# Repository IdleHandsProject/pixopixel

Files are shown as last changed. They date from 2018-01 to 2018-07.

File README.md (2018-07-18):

# The PIXO Pixel
PIXO Pixel is a 16 x 16 RGB LED display that runs off of an ESP32.

This project is open source! 

If you want to build this yourself, you can find the Bill of Materials [here](https://www.findchips.com/org/10-open-hardware/list/85998-pixo-pixel-esp-board-and-led-board) on FindChips.

I have submitted a pull request to the Arduino-ESP32 github: https://github.com/espressif/arduino-esp32 to have the PIXO Pixel have its own board file. This will ensure the pinout that was used will match the pin declartion on the board. In the meantime, please use the "Adafruit Feather ESP32" in the board manager, as the pinout is the same.

## Flashing Firmware Instructions
1. You need to have the current version of the [Arduino IDE](https://arduino.cc) installed
2. Ensure that you have the [Arduino ESP32 Boards](https://github.com/espressif/arduino-esp32) installed (This library is currently broken, a workaround has been found [Here](https://github.com/espressif/arduino-esp32/issues/1559))
3. Various other libraries are required for the example firmware; they are listed below under "Libraries used in Example Firmware"
4. Connect your pixo pixel to your computer and start Arduino
5. Under the "Tools" menu, select "Board->Adafruit ESP32 Feather"; Leave Flash frequency and Upload speed the default
6. Under Port, select the device your pixo is communicating over
7. Compile and upload
8. When the Arduino console says "Connecting....", press and hold both the boot and reset buttons simultaniously for 1 second; then release both buttons
9. You should start to see output about flashing
10. When the flash is complete, press the reset button on the pixo to start your new firmware

[Here](https://youtu.be/dVT4Nei8qHg) is a video of Sean going into detail demonstrating some of the examples

## Libraries used in Example Firmware
Install these to your sketchbook's `libraries` folder, usually located in `YOUR HOME/Documents/Arduino`

* [Adafruit GFX](https://github.com/adafruit/Adafruit-GFX-Library)
* [Adafruit DotStar](https://github.com/adafruit/Adafruit_DotStar)
* [Adafruit DotStar Matrix](https://github.com/adafruit/Adafruit_DotStarMatrix)
* [ArduinoJson](https://github.com/bblanchon/ArduinoJson)
* [i2cdevlib](https://github.com/jrowberg/i2cdevlib)

**Note** Arduino IDE was complaining about i2cdevlib being invalid as the installation instructions are a bit unclear.
It seems that the ESP32 is not officially supported for use with these libraries, and I had to apply a patch ([#367](https://github.com/jrowberg/i2cdevlib/pull/367)) to get no compile errors.

### Patching I2Cdev and MPU6050 Libraries
1. Download i2cdevlib and extract the zip file
2. Inside the i2cdevlib/Arduino folder, copy `I2Cdev` and `MPU6050` folders to your `libraries` folder
3. Edit `libraries/I2Cdev/I2Cdev.cpp`, and immedietly under `#include "I2Cdev.h"`, add the following
```
#ifdef ARDUINO_ARCH_ESP32
#define BUFFER_LENGTH I2C_BUFFER_LENGTH
#endif
```
4. Edit `libraries/MPU6050/MPU6050_6Axis_MotionApps20.h` and add the following right above the `DEBUG` section
```
#ifndef ARDUINO_ARCH_ESP32
    typedef void prog_void;
    typedef char prog_char;
    typedef unsigned char prog_uchar;
    typedef int8_t prog_int8_t;
    typedef uint8_t prog_uint8_t;
    typedef int16_t prog_int16_t;
    typedef uint16_t prog_uint16_t;
    typedef int32_t prog_int32_t;
    typedef uint32_t prog_uint32_t;
#endif
```
5. Restart Arduino

There's a whole bunch of other commits in here, but this seems mostly to be a mix of: feature adding, bug fixing, and various other changes that may or may not be related. Feel free to experiment with these at your own discretion.

## Kickstarter - Success
This was a [Make100 Kickstarter](https://www.kickstarter.com/projects/idlehandsdev/pixo-pixel-an-esp32-based-iot-rgb-display-for-make) that was recently fulfilled

Kickstarter Vid (https://youtu.be/XT5R4Tftu7k)

[Completion Video](https://youtu.be/YA3uAYVbMNc)

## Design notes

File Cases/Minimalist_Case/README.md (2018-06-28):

# A Minimalist Case for the PIXO Pixel

There is only a port for power - buttons and USB programming are covered up with this case, but it could be easily modified to make them more accessible.

This case can also be downloaded from [Thingiverse](https://www.thingiverse.com/thing:2974680)

## Assembly Instructions

1) Remove all hardware that came with the PIXO Pixel
2) Screw 4x M3x6 standoffs into the base of the "Case" part and secure with an M3 nut
3) Place bottom board of PIXO Pixel into case, and secure with 4x M3x15 standoffs
4) Place upper board of PIXO Pixel on standoffs
5) Place "Bezel" part on top of upper board
6) Secure with M3 screws of appropriate length (I used M3x12 button head screws)

Plug in power and enjoy!

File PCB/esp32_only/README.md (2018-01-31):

# ESPEverywhere
ESP8266 Special Make/100 Kickstarter Edition

ESP Everywhere

Check out why this board exists here:
https://www.youtube.com/watch?v=67Kh_ikb-ds

The ESP Everywhere was made to take part in the Kickstarter Make/100 Campaign
You can get 1 of 100 boards assembled by me. Or you can Make your own.
Kickstarter is here:
https://www.kickstarter.com/projects/idlehandsdev/esp-everywhere-kickstarter-special-make-100

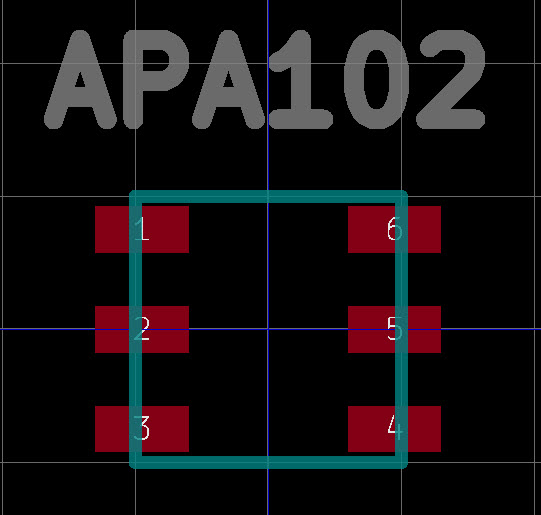
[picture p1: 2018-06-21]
PCB/pixel/Docs/new_apa102.jpg

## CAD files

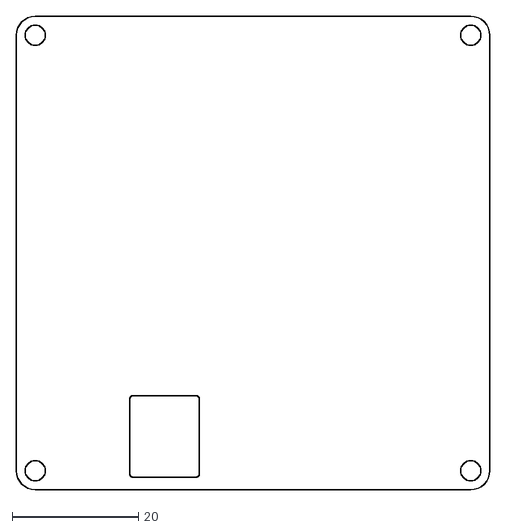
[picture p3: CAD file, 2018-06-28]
CAD/PIXO_ESP.dxf
75.0 x 75.0

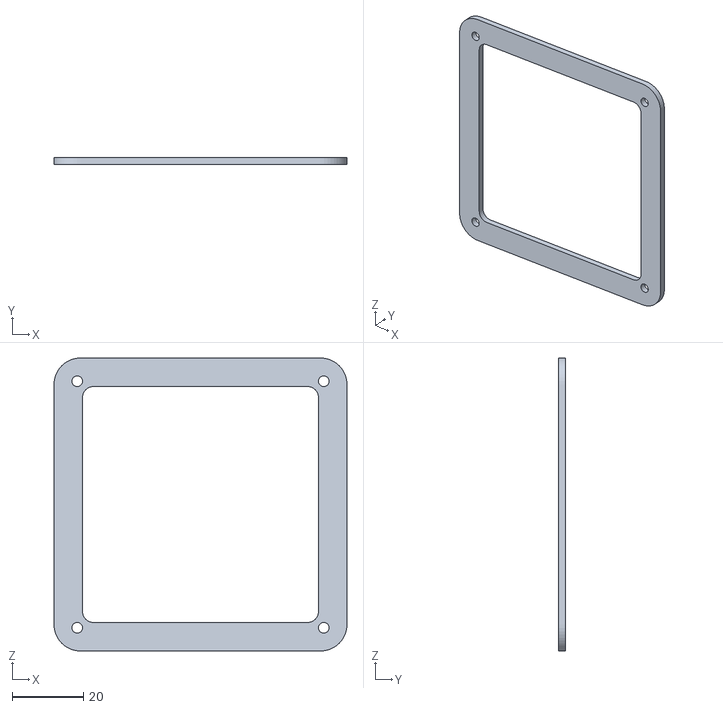
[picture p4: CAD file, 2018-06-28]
Cases/Minimalist_Case/PIXO_Bezel.stl
82.0 x 2.00 x 82.0

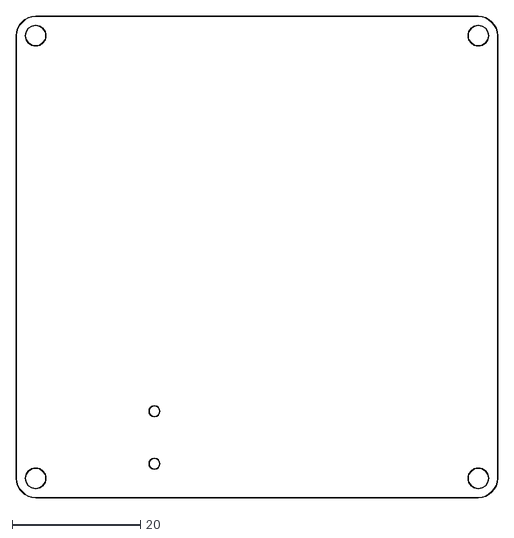
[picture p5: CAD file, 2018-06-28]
CAD/PIXO_Pixel.dxf
75.0 x 75.0

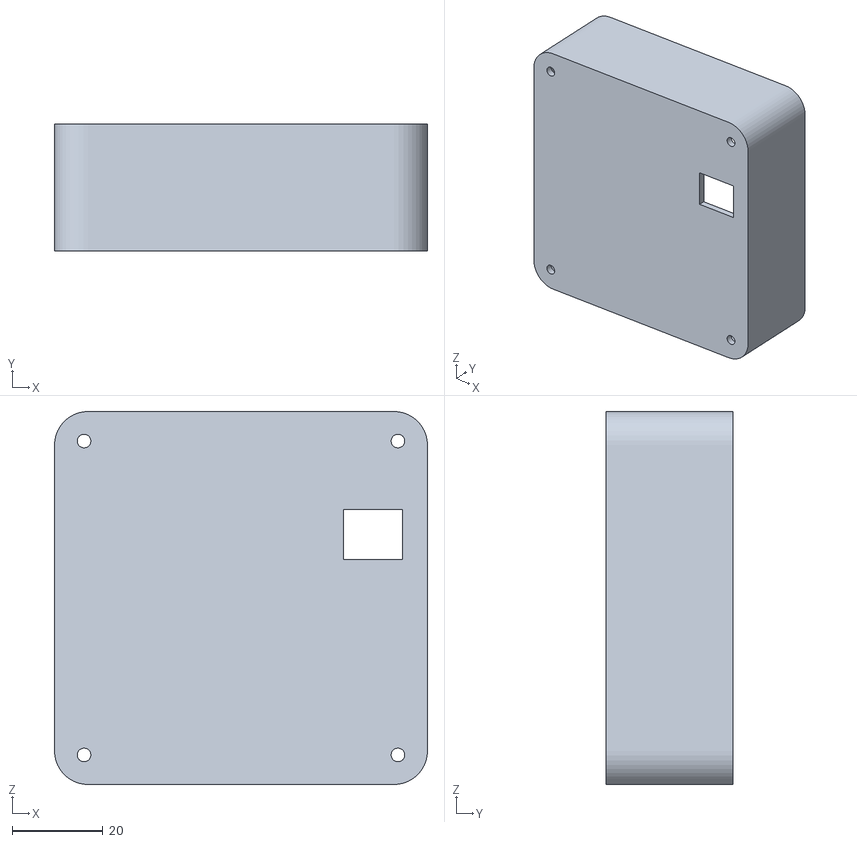
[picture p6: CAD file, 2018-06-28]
Cases/Minimalist_Case/PIXO_Case.stl
82.0 x 28.0 x 82.0

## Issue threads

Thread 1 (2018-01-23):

Switch Pins on DIODES D1 D2

hodginsa, 2018-01-23:
As always, diodes are reversed compared to the directional line.

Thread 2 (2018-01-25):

No Ground on Pixel 236

hodginsa, 2018-01-25:

hodginsa, 2018-02-20:
Ground has been fixed.

Closed 2018-02-20.

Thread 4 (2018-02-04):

Ground surrounding antenna

janekm, 2018-02-04:
While the ground is cleared right underneath the antenna, there is still a ground loop surrounding it. It would be better to move the module right up to the edge of the PCB, or at least clear the ground plane right up to the edge of the PCB, for antenna performance. Great project btw, I've also looked at these little LEDs and thought it'd be great to make a little display with them :)

hodginsa, 2018-02-20:
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
The ground plane was already to the edge, but I may be misinterpreting what you mean. Anyway, I have also widened the keepout to free up the antenna a bit more. :) Thanks!

janekm, 2018-02-21:
I think I was looking at an old version of the gerbers, sorry. Certainly looks better now!

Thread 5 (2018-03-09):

'A1' was not declared in this scope

LilyGO, 2018-03-09:
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

chunkysteveo, 2018-03-09:
Looks like he's used a different board declaration for the "pinouts".

Steve

hodginsa, 2018-04-19:
When I was testing I was using the Adafruit ESP32 Feather. However, that analog pin is just for "random" use, so any unconnected analog pin will work.

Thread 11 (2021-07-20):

Can it be implemented in a project about Parchis/Parks?

ImanCol, 2021-07-20:
I am doing a project that uses Arduino and we came up with converting a Ludo game board called Parchis / Parques with ws2812b LEDs.

In total, it would take us almost 600 of these RGB LEDs.  And I'm scratching my head on how to turn each 1 through a Bluetooth module to an Apple where it will contain the intelligence of the programmed game.  The idea is that every time someone moves a tile, the board with the LEDs reflects the same movement.

I don't really know if Arduino can handle that much data so I was wondering if your project can handle this with ease.  Although I have not fully studied its operation and handle a large number of LEDs, I appreciate any help.

https://upload.wikimedia.org/wikipedia/commons/e/e1/Parcheesi.svg

chunkysteveo, 2021-07-20:
The ESP is more than capable of turning on and off 600 addressable LEDs. But the Pixo only has 256 leds, not 600.

ImanCol, 2021-07-25:
I have researched it and it seems ideal for the project.  Thanks.

Closed 2021-07-25.

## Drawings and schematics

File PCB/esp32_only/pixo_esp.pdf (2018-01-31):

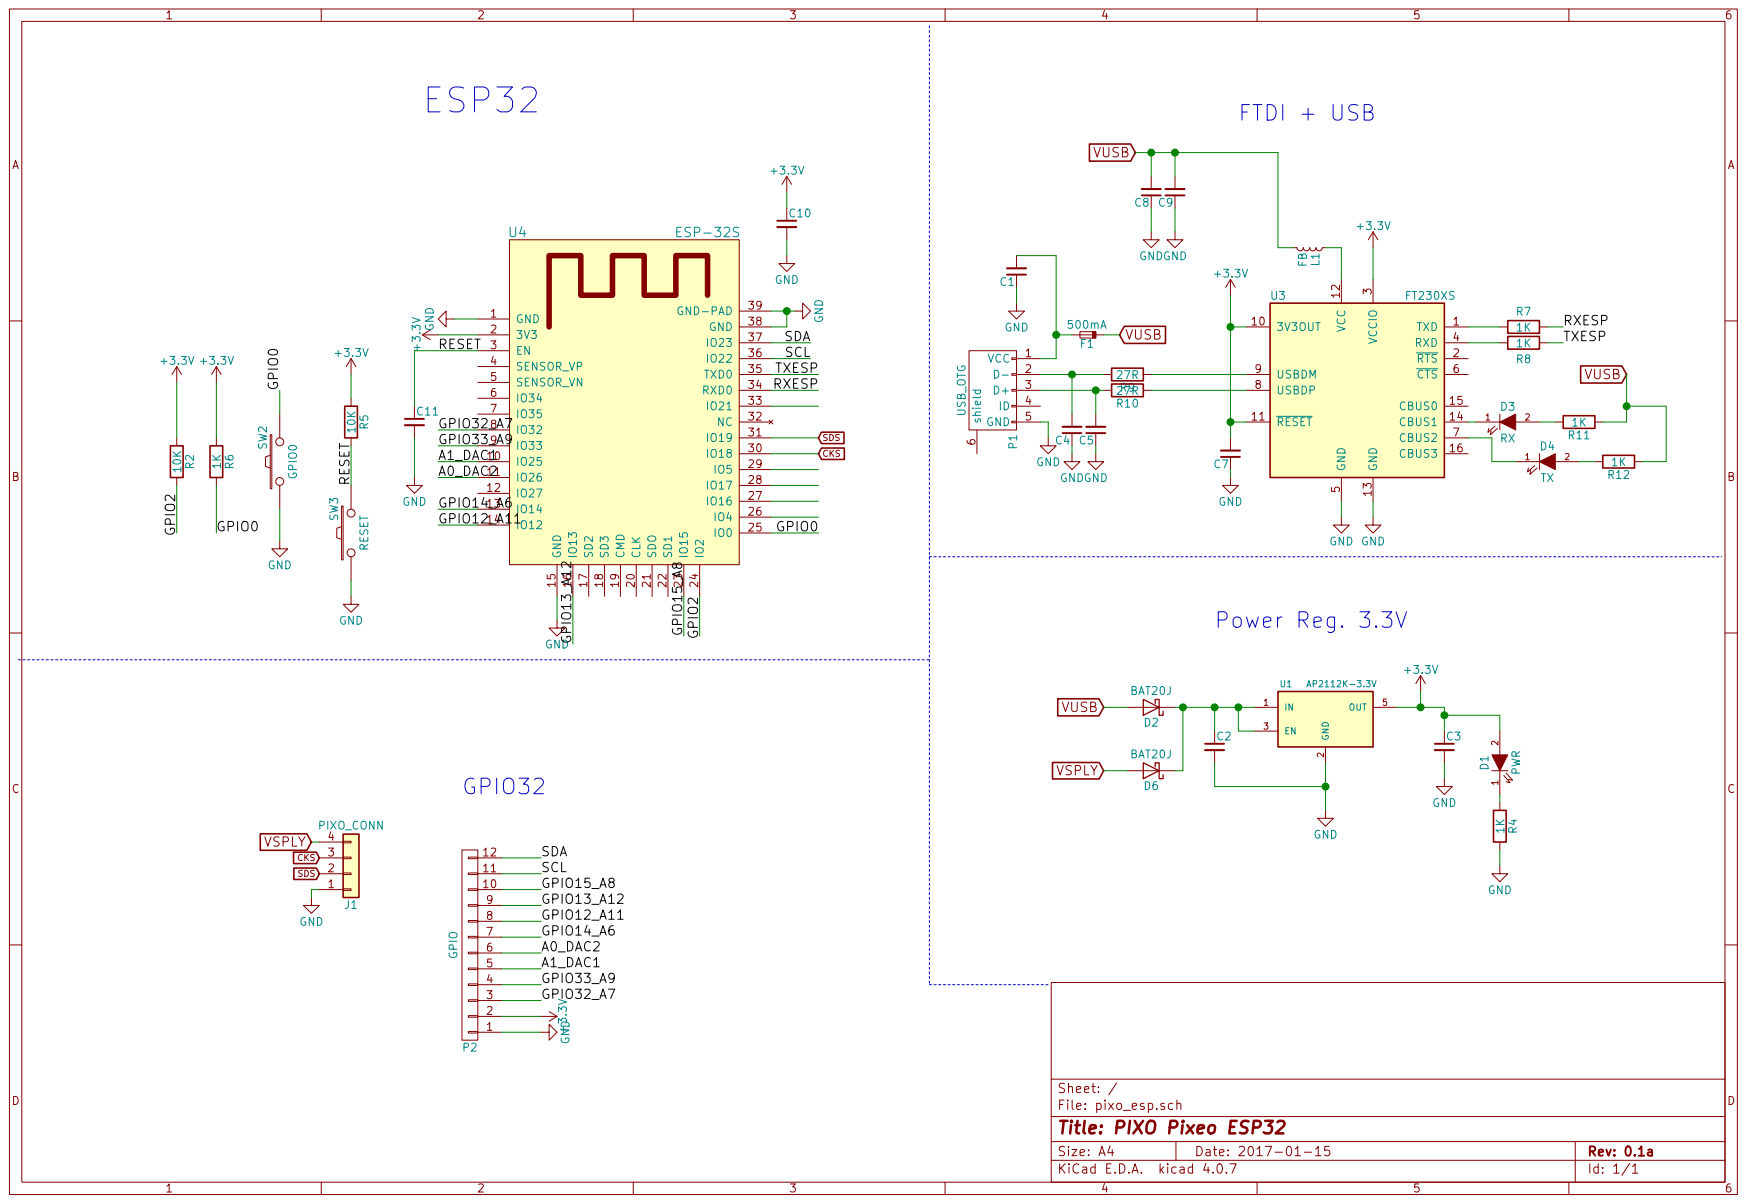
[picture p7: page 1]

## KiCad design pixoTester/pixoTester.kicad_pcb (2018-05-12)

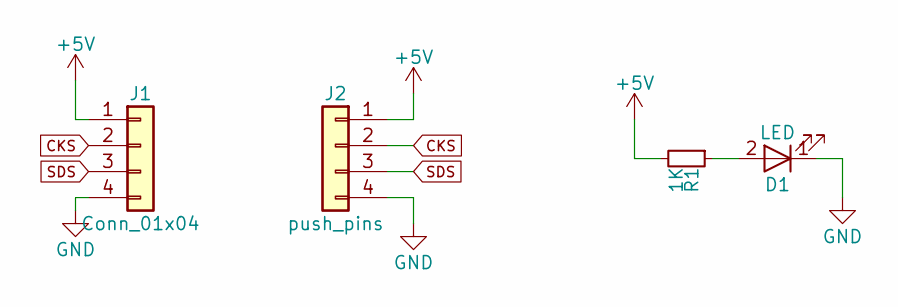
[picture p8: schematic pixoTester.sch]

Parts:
D1: LED; LED-0603
J1: Conn_01x04; Connectors_JST_S4B-PH-SM4-TB
J2: push_pins; pixo_testpins
R1: 1K; R_0805

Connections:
+5V: J1.1, J2.1, R1.2
CKS: J1.2, J2.2
GND: D1.1 (K), J1.4, J2.4
unnamed: D1.2 (A), R1.1
SDS: J1.3, J2.3

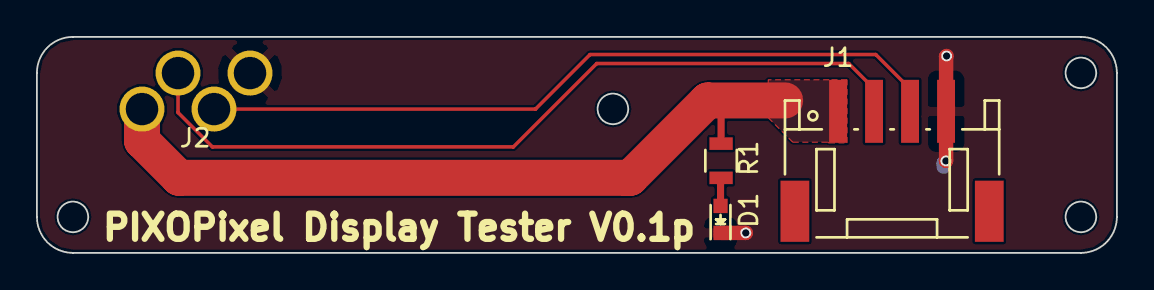
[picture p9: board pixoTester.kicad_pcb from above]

Board: 2 copper layers, 60.0 x 12.0 mm, 4 parts (0 on the bottom side), 5 nets.

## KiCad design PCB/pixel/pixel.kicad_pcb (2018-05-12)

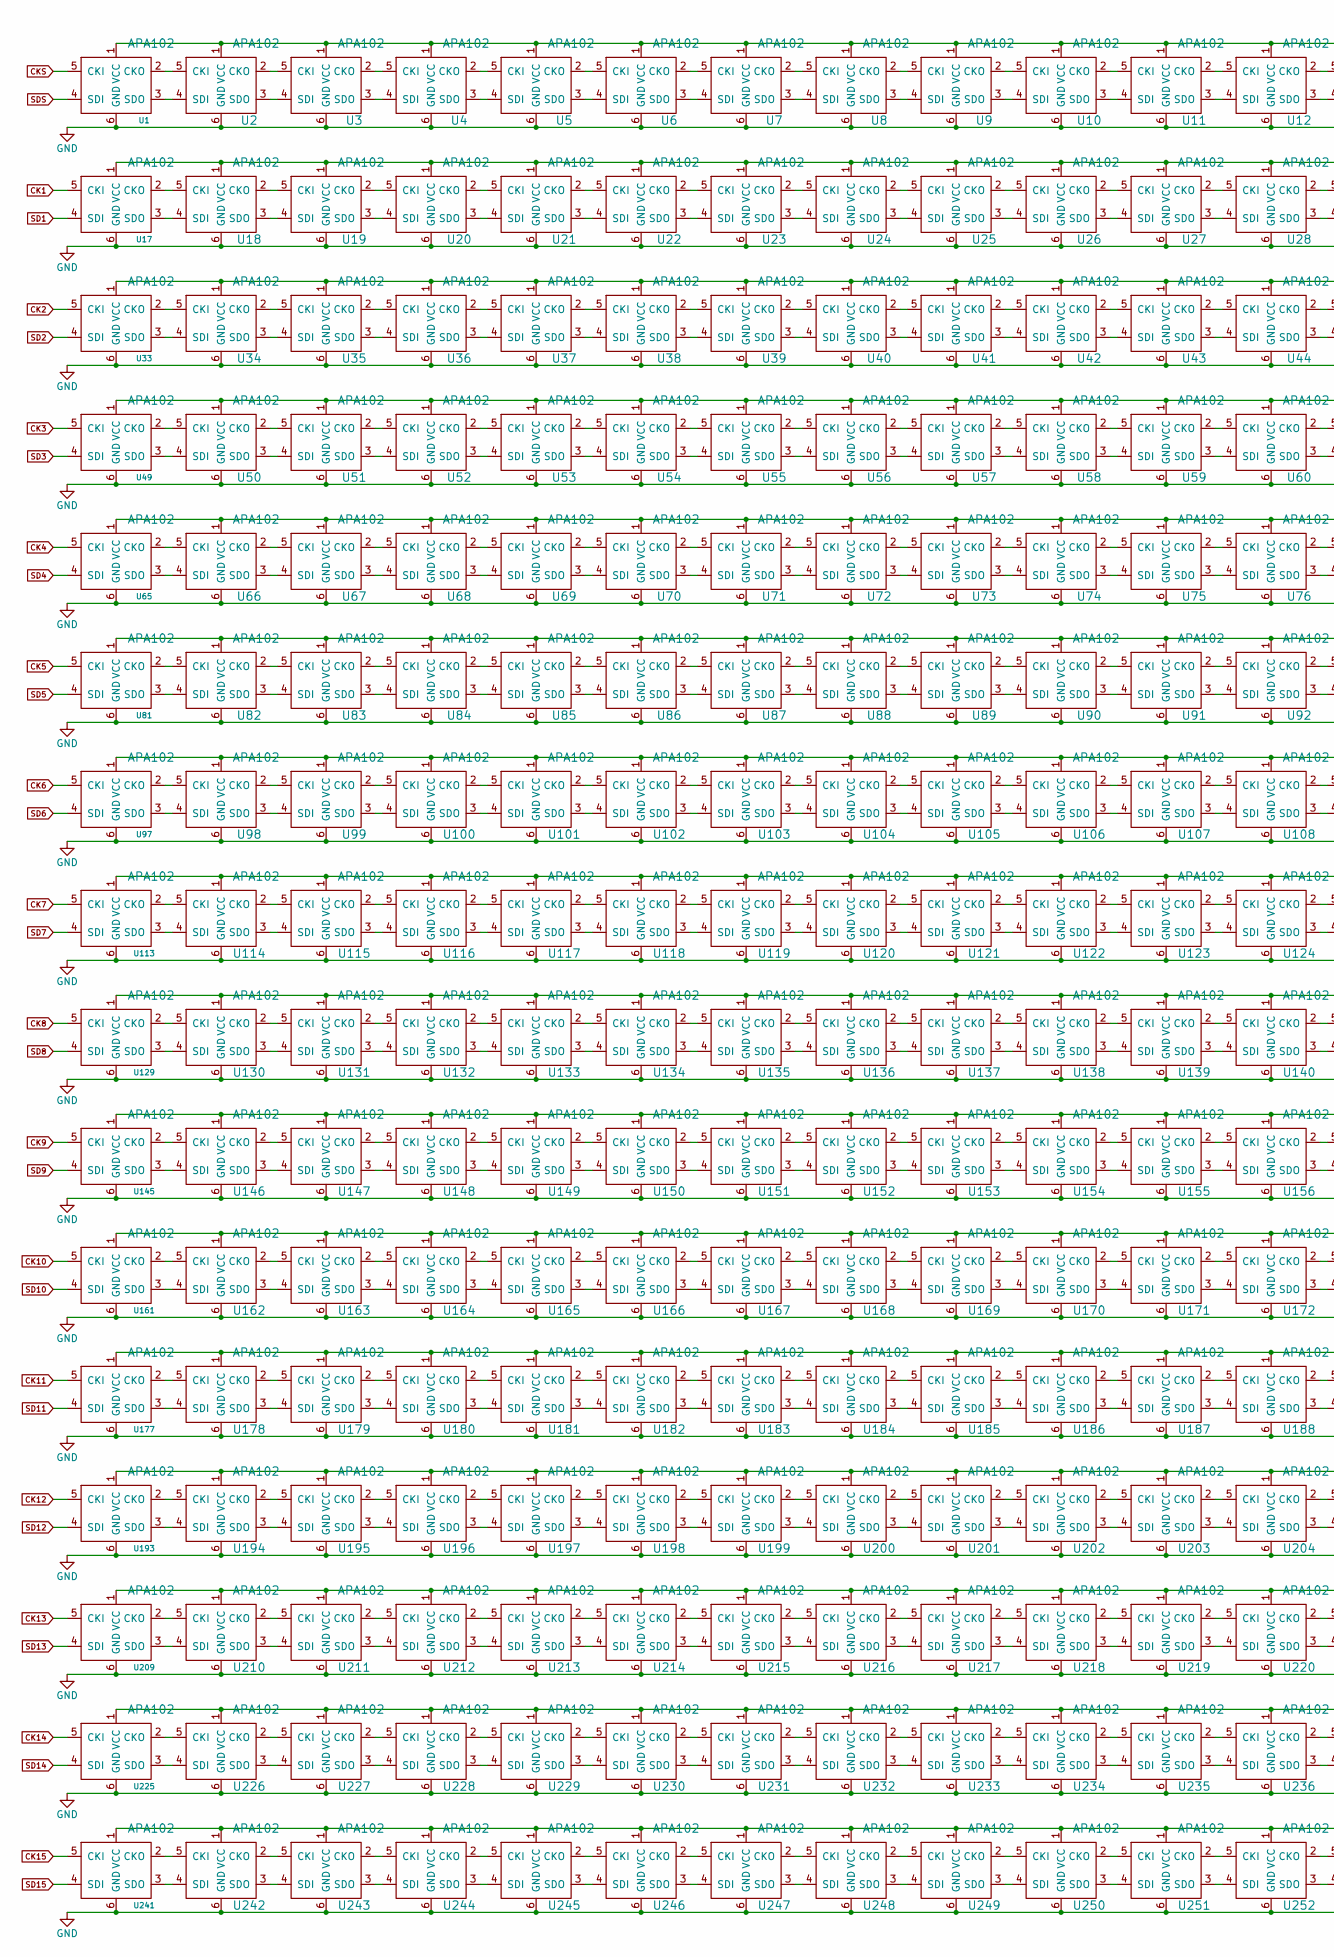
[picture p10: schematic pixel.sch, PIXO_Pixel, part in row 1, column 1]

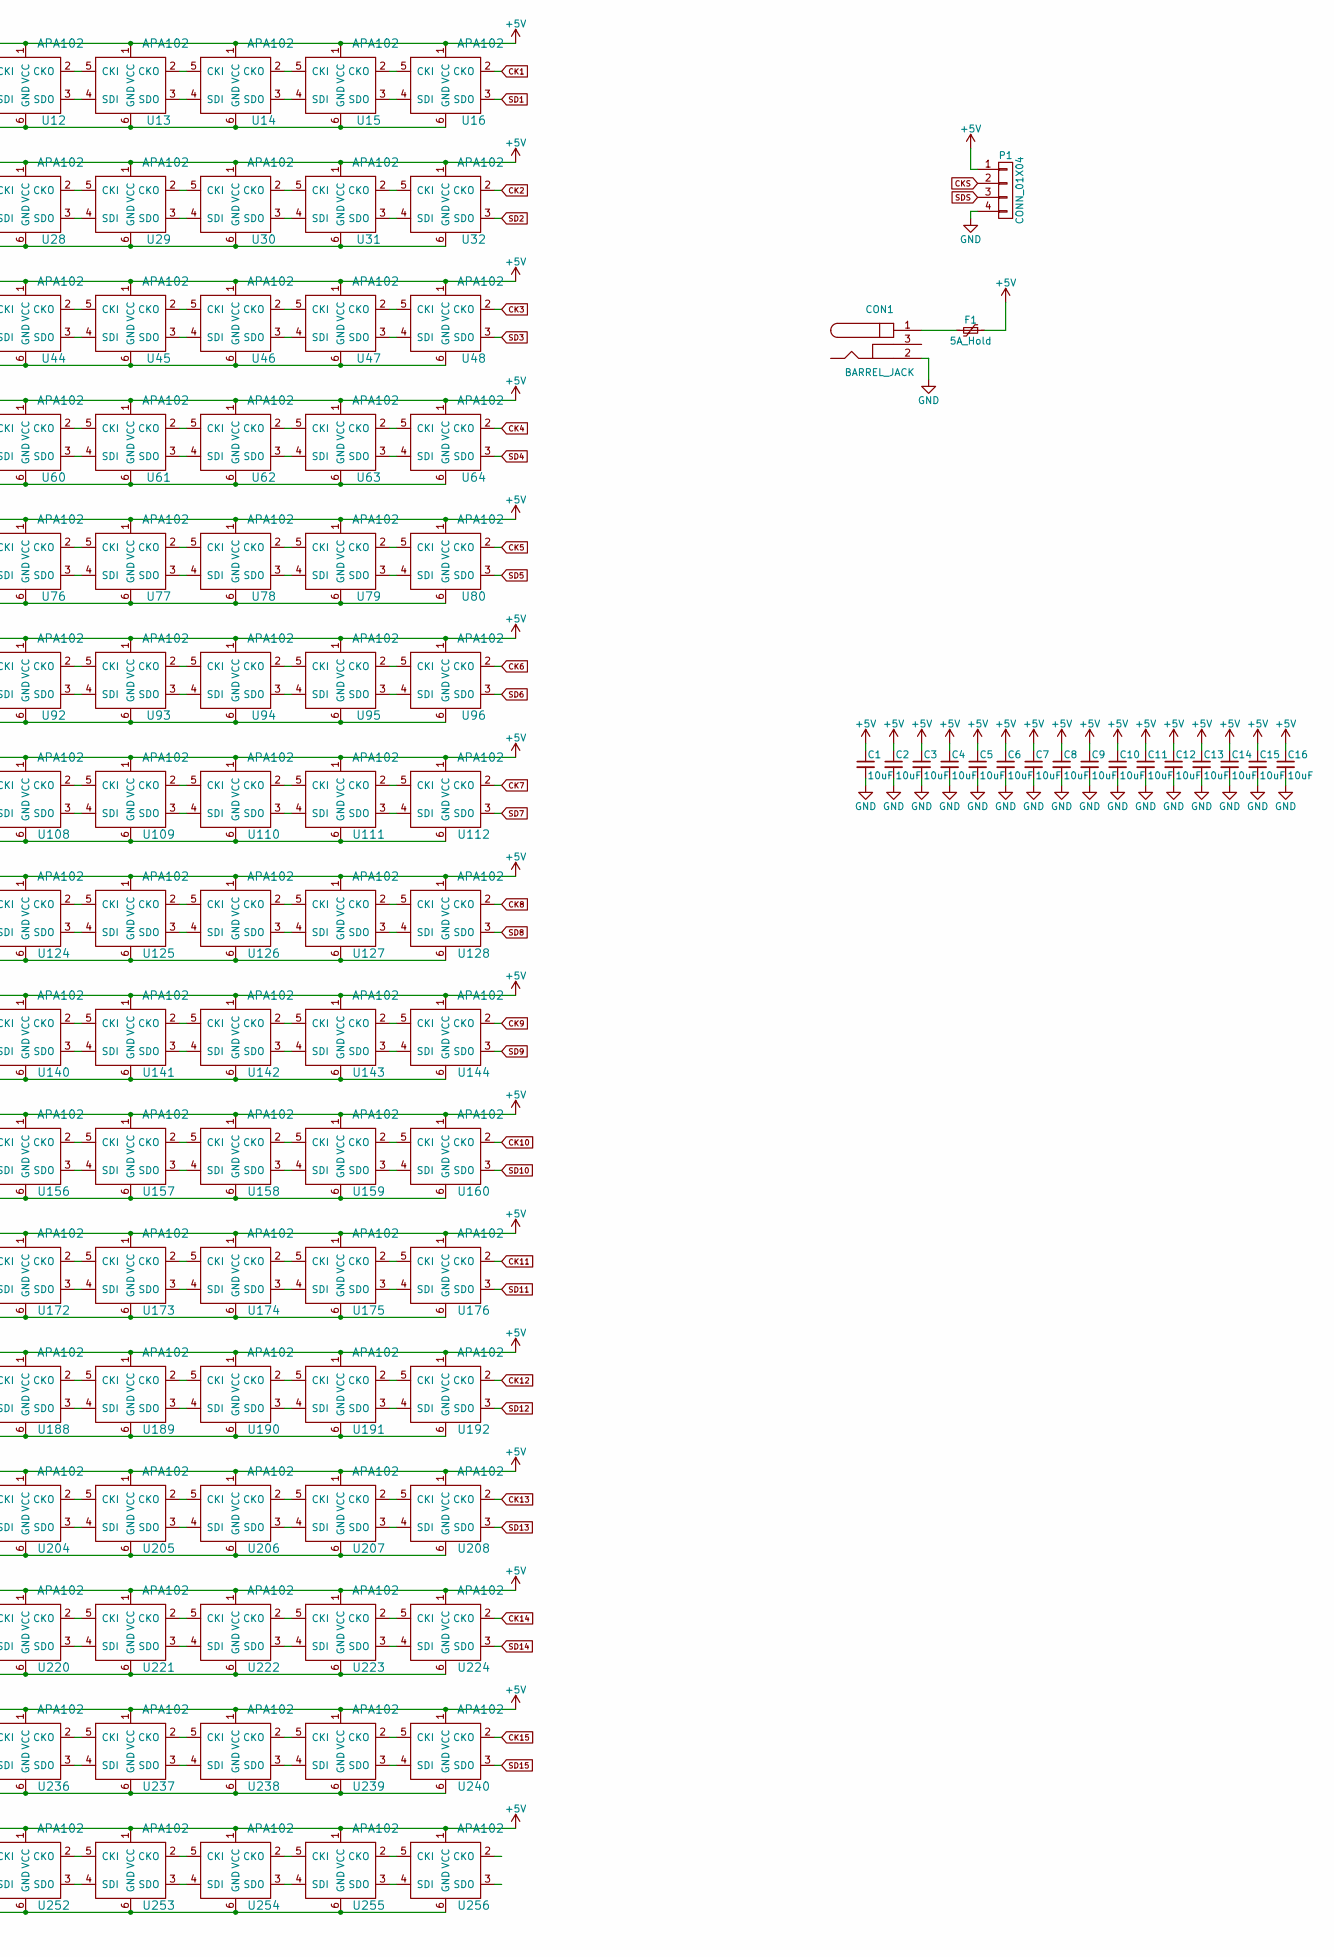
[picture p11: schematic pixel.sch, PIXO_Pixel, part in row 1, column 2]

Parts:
C1: 10uF; c_1206; Digikey Part No. 490-3340-1-ND
C2, C3, C4, C5, C6, C7, C8, C9, C10, C11, C12, C13, C14, C15, C16: 10uF; c_1206; Digikey Part No. 490-5525-1-ND
CON1: BARREL_JACK; DC_POWERJACK_VERT_NoHoles; Digikey Part No. CP-006APJCT-ND
F1: 5A_Hold; Fuse_SMD1206_Reflow; Digikey Part No. MF-USML400-2CT-ND
P1: CONN_01X04; Connectors_JST_S4B-PH-SM4-TB; Digikey Part No. 455-1751-1-ND
U1, U2, U3, U4, U5, U6, U7, U8, U9, U10, U11, U12, U13, U14, U15, U16, U17, U18, U19, U20, U21, U22, U23, U24, U25, U26, U27, U28, U29, U30, U31, U32, U33, U34, U35, U36, U37, U38, U39, U40, U41, U42, U43, U44, U45, U46, U47, U48, U49, U50, U51, U52, U53, U54, U55, U56, U57, U58, U59, U60, U61, U62, U63, U64, U65, U66, U67, U68, U69, U70, U71, U72, U73, U74, U75, U76, U77, U78, U79, U80, U81, U82, U83, U84, U85, U86, U87, U88, U89, U90, U91, U92, U93, U94, U95, U96, U97, U98, U99, U100, U101, U102, U103, U104, U105, U106, U107, U108, U109, U110, U111, U112, U113, U114, U115, U116, U117, U118, U119, U120, U121, U122, U123, U124, U125, U126, U127, U128, U129, U130, U131, U132, U133, U134, U135, U136, U137, U138, U139, U140, U141, U142, U143, U144, U145, U146, U147, U148, U149, U150, U151, U152, U153, U154, U155, U156, U157, U158, U159, U160, U161, U162, U163, U164, U165, U166, U167, U168, U169, U170, U171, U172, U173, U174, U175, U176, U177, U178, U179, U180, U181, U182, U183, U184, U185, U186, U187, U188, U189, U190, U191, U192, U193, U194, U195, U196, U197, U198, U199, U200, U201, U202, U203, U204, U205, U206, U207, U208, U209, U210, U211, U212, U213, U214, U215, U216, U217, U218, U219, U220, U221, U222, U223, U224, U225, U226, U227, U228, U229, U230, U231, U232, U233, U234, U235, U236, U237, U238, U239, U240, U241, U242, U243, U244, U245, U246, U247, U248, U249, U250, U251, U252, U253, U254, U255, U256: APA102; APA102-2020_AFSTYLE

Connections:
+5V: C1.1, C2.1, C3.1, C4.1, C5.1, C6.1, C7.1, C8.1, C9.1, C10.1, C11.1, C12.1, C13.1, C14.1, C15.1, C16.1, F1.1, P1.1, U1.1 (VCC), U2.1 (VCC), U3.1 (VCC), U4.1 (VCC), U5.1 (VCC), U6.1 (VCC), U7.1 (VCC), U8.1 (VCC), U9.1 (VCC), U10.1 (VCC), U11.1 (VCC), U12.1 (VCC), U13.1 (VCC), U14.1 (VCC), U15.1 (VCC), U16.1 (VCC), U17.1 (VCC), U18.1 (VCC), U19.1 (VCC), U20.1 (VCC), U21.1 (VCC), U22.1 (VCC), U23.1 (VCC), U24.1 (VCC), U25.1 (VCC), U26.1 (VCC), U27.1 (VCC), U28.1 (VCC), U29.1 (VCC), U30.1 (VCC), U31.1 (VCC), U32.1 (VCC), U33.1 (VCC), U34.1 (VCC), U35.1 (VCC), U36.1 (VCC), U37.1 (VCC), U38.1 (VCC), U39.1 (VCC), U40.1 (VCC), U41.1 (VCC), U42.1 (VCC), U43.1 (VCC), U44.1 (VCC), U45.1 (VCC), U46.1 (VCC), U47.1 (VCC), U48.1 (VCC), U49.1 (VCC), U50.1 (VCC), U51.1 (VCC), U52.1 (VCC), U53.1 (VCC), U54.1 (VCC), U55.1 (VCC), U56.1 (VCC), U57.1 (VCC), U58.1 (VCC), U59.1 (VCC), U60.1 (VCC), U61.1 (VCC), U62.1 (VCC), U63.1 (VCC), U64.1 (VCC), U65.1 (VCC), U66.1 (VCC), U67.1 (VCC), U68.1 (VCC), U69.1 (VCC), U70.1 (VCC), U71.1 (VCC), U72.1 (VCC), U73.1 (VCC), U74.1 (VCC), U75.1 (VCC), U76.1 (VCC), U77.1 (VCC), U78.1 (VCC), U79.1 (VCC), U80.1 (VCC), U81.1 (VCC), U82.1 (VCC), U83.1 (VCC), U84.1 (VCC), U85.1 (VCC), U86.1 (VCC), U87.1 (VCC), U88.1 (VCC), U89.1 (VCC), U90.1 (VCC), U91.1 (VCC), U92.1 (VCC), U93.1 (VCC), U94.1 (VCC), U95.1 (VCC), U96.1 (VCC), U97.1 (VCC), U98.1 (VCC), U99.1 (VCC), U100.1 (VCC), U101.1 (VCC), U102.1 (VCC), U103.1 (VCC), U104.1 (VCC), U105.1 (VCC), U106.1 (VCC), U107.1 (VCC), U108.1 (VCC), U109.1 (VCC), U110.1 (VCC), U111.1 (VCC), U112.1 (VCC), U113.1 (VCC), U114.1 (VCC), U115.1 (VCC), U116.1 (VCC), U117.1 (VCC), U118.1 (VCC), U119.1 (VCC), U120.1 (VCC), U121.1 (VCC), U122.1 (VCC), U123.1 (VCC), U124.1 (VCC), U125.1 (VCC), U126.1 (VCC), U127.1 (VCC), U128.1 (VCC), U129.1 (VCC), U130.1 (VCC), U131.1 (VCC), U132.1 (VCC), U133.1 (VCC), U134.1 (VCC), U135.1 (VCC), U136.1 (VCC), U137.1 (VCC), U138.1 (VCC), U139.1 (VCC), U140.1 (VCC), U141.1 (VCC), U142.1 (VCC), U143.1 (VCC), U144.1 (VCC), U145.1 (VCC), U146.1 (VCC), U147.1 (VCC), U148.1 (VCC), U149.1 (VCC), U150.1 (VCC), U151.1 (VCC), U152.1 (VCC), U153.1 (VCC), U154.1 (VCC), U155.1 (VCC), U156.1 (VCC), U157.1 (VCC), U158.1 (VCC), U159.1 (VCC), U160.1 (VCC), U161.1 (VCC), U162.1 (VCC), U163.1 (VCC), U164.1 (VCC), U165.1 (VCC), U166.1 (VCC), U167.1 (VCC), U168.1 (VCC), U169.1 (VCC), U170.1 (VCC), U171.1 (VCC), U172.1 (VCC), U173.1 (VCC), U174.1 (VCC), U175.1 (VCC), U176.1 (VCC), U177.1 (VCC), U178.1 (VCC), U179.1 (VCC), U180.1 (VCC), U181.1 (VCC), U182.1 (VCC), U183.1 (VCC), U184.1 (VCC), U185.1 (VCC), U186.1 (VCC), U187.1 (VCC), U188.1 (VCC), U189.1 (VCC), U190.1 (VCC), U191.1 (VCC), U192.1 (VCC), U193.1 (VCC), U194.1 (VCC), U195.1 (VCC), U196.1 (VCC), U197.1 (VCC), U198.1 (VCC), U199.1 (VCC), U200.1 (VCC), U201.1 (VCC), U202.1 (VCC), U203.1 (VCC), U204.1 (VCC), U205.1 (VCC), U206.1 (VCC), U207.1 (VCC), U208.1 (VCC), U209.1 (VCC), U210.1 (VCC), U211.1 (VCC), U212.1 (VCC), U213.1 (VCC), U214.1 (VCC), U215.1 (VCC), U216.1 (VCC), U217.1 (VCC), U218.1 (VCC), U219.1 (VCC), U220.1 (VCC), U221.1 (VCC), U222.1 (VCC), U223.1 (VCC), U224.1 (VCC), U225.1 (VCC), U226.1 (VCC), U227.1 (VCC), U228.1 (VCC), U229.1 (VCC), U230.1 (VCC), U231.1 (VCC), U232.1 (VCC), U233.1 (VCC), U234.1 (VCC), U235.1 (VCC), U236.1 (VCC), U237.1 (VCC), U238.1 (VCC), U239.1 (VCC), U240.1 (VCC), U241.1 (VCC), U242.1 (VCC), U243.1 (VCC), U244.1 (VCC), U245.1 (VCC), U246.1 (VCC), U247.1 (VCC), U248.1 (VCC), U249.1 (VCC), U250.1 (VCC)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
CK1: U16.2 (CKO), U17.5 (CKI)
CK2: U32.2 (CKO), U33.5 (CKI)
CK3: U48.2 (CKO), U49.5 (CKI)
CK4: U64.2 (CKO), U65.5 (CKI)
CK5: U80.2 (CKO), U81.5 (CKI)
CK6: U96.2 (CKO), U97.5 (CKI)
CK7: U112.2 (CKO), U113.5 (CKI)
CK8: U128.2 (CKO), U129.5 (CKI)
CK9: U144.2 (CKO), U145.5 (CKI)
CK10: U160.2 (CKO), U161.5 (CKI)
CK11: U176.2 (CKO), U177.5 (CKI)
CK12: U192.2 (CKO), U193.5 (CKI)
CK13: U208.2 (CKO), U209.5 (CKI)
CK14: U224.2 (CKO), U225.5 (CKI)
CK15: U240.2 (CKO), U241.5 (CKI)
CKS: P1.2, U1.5 (CKI)
GND: C1.2, C2.2, C3.2, C4.2, C5.2, C6.2, C7.2, C8.2, C9.2, C10.2, C11.2, C12.2, C13.2, C14.2, C15.2, C16.2, CON1.2, P1.4, U1.6 (GND), U2.6 (GND), U3.6 (GND), U4.6 (GND), U5.6 (GND), U6.6 (GND), U7.6 (GND), U8.6 (GND), U9.6 (GND), U10.6 (GND), U11.6 (GND), U12.6 (GND), U13.6 (GND), U14.6 (GND), U15.6 (GND), U16.6 (GND), U17.6 (GND), U18.6 (GND), U19.6 (GND), U20.6 (GND), U21.6 (GND), U22.6 (GND), U23.6 (GND), U24.6 (GND), U25.6 (GND), U26.6 (GND), U27.6 (GND), U28.6 (GND), U29.6 (GND), U30.6 (GND), U31.6 (GND), U32.6 (GND), U33.6 (GND), U34.6 (GND), U35.6 (GND), U36.6 (GND), U37.6 (GND), U38.6 (GND), U39.6 (GND), U40.6 (GND), U41.6 (GND), U42.6 (GND), U43.6 (GND), U44.6 (GND), U45.6 (GND), U46.6 (GND), U47.6 (GND), U48.6 (GND), U49.6 (GND), U50.6 (GND), U51.6 (GND), U52.6 (GND), U53.6 (GND), U54.6 (GND), U55.6 (GND), U56.6 (GND), U57.6 (GND), U58.6 (GND), U59.6 (GND), U60.6 (GND), U61.6 (GND), U62.6 (GND), U63.6 (GND), U64.6 (GND), U65.6 (GND), U66.6 (GND), U67.6 (GND), U68.6 (GND), U69.6 (GND), U70.6 (GND), U71.6 (GND), U72.6 (GND), U73.6 (GND), U74.6 (GND), U75.6 (GND), U76.6 (GND), U77.6 (GND), U78.6 (GND), U79.6 (GND), U80.6 (GND), U81.6 (GND), U82.6 (GND), U83.6 (GND), U84.6 (GND), U85.6 (GND), U86.6 (GND), U87.6 (GND), U88.6 (GND), U89.6 (GND), U90.6 (GND), U91.6 (GND), U92.6 (GND), U93.6 (GND), U94.6 (GND), U95.6 (GND), U96.6 (GND), U97.6 (GND), U98.6 (GND), U99.6 (GND), U100.6 (GND), U101.6 (GND), U102.6 (GND), U103.6 (GND), U104.6 (GND), U105.6 (GND), U106.6 (GND), U107.6 (GND), U108.6 (GND), U109.6 (GND), U110.6 (GND), U111.6 (GND), U112.6 (GND), U113.6 (GND), U114.6 (GND), U115.6 (GND), U116.6 (GND), U117.6 (GND), U118.6 (GND), U119.6 (GND), U120.6 (GND), U121.6 (GND), U122.6 (GND), U123.6 (GND), U124.6 (GND), U125.6 (GND), U126.6 (GND), U127.6 (GND), U128.6 (GND), U129.6 (GND), U130.6 (GND), U131.6 (GND), U132.6 (GND), U133.6 (GND), U134.6 (GND), U135.6 (GND), U136.6 (GND), U137.6 (GND), U138.6 (GND), U139.6 (GND), U140.6 (GND), U141.6 (GND), U142.6 (GND), U143.6 (GND), U144.6 (GND), U145.6 (GND), U146.6 (GND), U147.6 (GND), U148.6 (GND), U149.6 (GND), U150.6 (GND), U151.6 (GND), U152.6 (GND), U153.6 (GND), U154.6 (GND), U155.6 (GND), U156.6 (GND), U157.6 (GND), U158.6 (GND), U159.6 (GND), U160.6 (GND), U161.6 (GND), U162.6 (GND), U163.6 (GND), U164.6 (GND), U165.6 (GND), U166.6 (GND), U167.6 (GND), U168.6 (GND), U169.6 (GND), U170.6 (GND), U171.6 (GND), U172.6 (GND), U173.6 (GND), U174.6 (GND), U175.6 (GND), U176.6 (GND), U177.6 (GND), U178.6 (GND), U179.6 (GND), U180.6 (GND), U181.6 (GND), U182.6 (GND), U183.6 (GND), U184.6 (GND), U185.6 (GND), U186.6 (GND), U187.6 (GND), U188.6 (GND), U189.6 (GND), U190.6 (GND), U191.6 (GND), U192.6 (GND), U193.6 (GND), U194.6 (GND), U195.6 (GND), U196.6 (GND), U197.6 (GND), U198.6 (GND), U199.6 (GND), U200.6 (GND), U201.6 (GND), U202.6 (GND), U203.6 (GND), U204.6 (GND), U205.6 (GND), U206.6 (GND), U207.6 (GND), U208.6 (GND), U209.6 (GND), U210.6 (GND), U211.6 (GND), U212.6 (GND), U213.6 (GND), U214.6 (GND), U215.6 (GND), U216.6 (GND), U217.6 (GND), U218.6 (GND), U219.6 (GND), U220.6 (GND), U221.6 (GND), U222.6 (GND), U223.6 (GND), U224.6 (GND), U225.6 (GND), U226.6 (GND), U227.6 (GND), U228.6 (GND), U229.6 (GND), U230.6 (GND), U231.6 (GND), U232.6 (GND), U233.6 (GND), U234.6 (GND), U235.6 (GND), U236.6 (GND), U237.6 (GND), U238.6 (GND), U239.6 (GND), U240.6 (GND), U241.6 (GND), U242.6 (GND), U243.6 (GND), U244.6 (GND), U245.6 (GND), U246.6 (GND), U247.6 (GND), U248.6 (GND), U249.6 (GND), U250.6 (GND)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
unnamed: CON1.1, F1.2
unnamed: U1.2 (CKO), U2.5 (CKI)
unnamed: U1.3 (SDO), U2.4 (SDI)
unnamed: U2.2 (CKO), U3.5 (CKI)
unnamed: U2.3 (SDO), U3.4 (SDI)
unnamed: U3.2 (CKO), U4.5 (CKI)
unnamed: U3.3 (SDO), U4.4 (SDI)
unnamed: U4.2 (CKO), U5.5 (CKI)
unnamed: U4.3 (SDO), U5.4 (SDI)
unnamed: U5.2 (CKO), U6.5 (CKI)
unnamed: U5.3 (SDO), U6.4 (SDI)
unnamed: U6.2 (CKO), U7.5 (CKI)
unnamed: U6.3 (SDO), U7.4 (SDI)
unnamed: U7.2 (CKO), U8.5 (CKI)
unnamed: U7.3 (SDO), U8.4 (SDI)
unnamed: U8.2 (CKO), U9.5 (CKI)
unnamed: U8.3 (SDO), U9.4 (SDI)
unnamed: U10.2 (CKO), U11.5 (CKI)
unnamed: U10.3 (SDO), U11.4 (SDI)
unnamed: U9.3 (SDO), U10.4 (SDI)
unnamed: U9.2 (CKO), U10.5 (CKI)
unnamed: U11.2 (CKO), U12.5 (CKI)
unnamed: U11.3 (SDO), U12.4 (SDI)
unnamed: U12.2 (CKO), U13.5 (CKI)
unnamed: U12.3 (SDO), U13.4 (SDI)
unnamed: U13.2 (CKO), U14.5 (CKI)
unnamed: U13.3 (SDO), U14.4 (SDI)
unnamed: U14.2 (CKO), U15.5 (CKI)
unnamed: U14.3 (SDO), U15.4 (SDI)
unnamed: U15.2 (CKO), U16.5 (CKI)
unnamed: U15.3 (SDO), U16.4 (SDI)
unnamed: U17.2 (CKO), U18.5 (CKI)
unnamed: U17.3 (SDO), U18.4 (SDI)
unnamed: U18.2 (CKO), U19.5 (CKI)
unnamed: U18.3 (SDO), U19.4 (SDI)
unnamed: U19.2 (CKO), U20.5 (CKI)
unnamed: U19.3 (SDO), U20.4 (SDI)
unnamed: U20.2 (CKO), U21.5 (CKI)
unnamed: U20.3 (SDO), U21.4 (SDI)
unnamed: U21.2 (CKO), U22.5 (CKI)
unnamed: U21.3 (SDO), U22.4 (SDI)
unnamed: U22.2 (CKO), U23.5 (CKI)
unnamed: U22.3 (SDO), U23.4 (SDI)
unnamed: U23.2 (CKO), U24.5 (CKI)
unnamed: U23.3 (SDO), U24.4 (SDI)
unnamed: U24.2 (CKO), U25.5 (CKI)
unnamed: U24.3 (SDO), U25.4 (SDI)
unnamed: U25.2 (CKO), U26.5 (CKI)
unnamed: U25.3 (SDO), U26.4 (SDI)
unnamed: U26.2 (CKO), U27.5 (CKI)
unnamed: U26.3 (SDO), U27.4 (SDI)
unnamed: U27.2 (CKO), U28.5 (CKI)
unnamed: U27.3 (SDO), U28.4 (SDI)
unnamed: U28.2 (CKO), U29.5 (CKI)
unnamed: U28.3 (SDO), U29.4 (SDI)
unnamed: U29.2 (CKO), U30.5 (CKI)
unnamed: U29.3 (SDO), U30.4 (SDI)
unnamed: U30.2 (CKO), U31.5 (CKI)
unnamed: U30.3 (SDO), U31.4 (SDI)
unnamed: U31.2 (CKO), U32.5 (CKI)
unnamed: U31.3 (SDO), U32.4 (SDI)
unnamed: U33.2 (CKO), U34.5 (CKI)
unnamed: U33.3 (SDO), U34.4 (SDI)
unnamed: U34.2 (CKO), U35.5 (CKI)
unnamed: U34.3 (SDO), U35.4 (SDI)
unnamed: U35.2 (CKO), U36.5 (CKI)
unnamed: U35.3 (SDO), U36.4 (SDI)
unnamed: U36.2 (CKO), U37.5 (CKI)
unnamed: U36.3 (SDO), U37.4 (SDI)
unnamed: U37.2 (CKO), U38.5 (CKI)
unnamed: U37.3 (SDO), U38.4 (SDI)
unnamed: U38.2 (CKO), U39.5 (CKI)
unnamed: U38.3 (SDO), U39.4 (SDI)
unnamed: U39.2 (CKO), U40.5 (CKI)
unnamed: U39.3 (SDO), U40.4 (SDI)
unnamed: U40.2 (CKO), U41.5 (CKI)
unnamed: U40.3 (SDO), U41.4 (SDI)
unnamed: U41.2 (CKO), U42.5 (CKI)
unnamed: U41.3 (SDO), U42.4 (SDI)
unnamed: U42.2 (CKO), U43.5 (CKI)
unnamed: U42.3 (SDO), U43.4 (SDI)
unnamed: U43.2 (CKO), U44.5 (CKI)
unnamed: U43.3 (SDO), U44.4 (SDI)
unnamed: U44.2 (CKO), U45.5 (CKI)
unnamed: U44.3 (SDO), U45.4 (SDI)
unnamed: U45.2 (CKO), U46.5 (CKI)
unnamed: U45.3 (SDO), U46.4 (SDI)
unnamed: U46.2 (CKO), U47.5 (CKI)
unnamed: U46.3 (SDO), U47.4 (SDI)
unnamed: U47.2 (CKO), U48.5 (CKI)
unnamed: U47.3 (SDO), U48.4 (SDI)
unnamed: U49.2 (CKO), U50.5 (CKI)
unnamed: U49.3 (SDO), U50.4 (SDI)
unnamed: U50.2 (CKO), U51.5 (CKI)
unnamed: U50.3 (SDO), U51.4 (SDI)
unnamed: U51.2 (CKO), U52.5 (CKI)
unnamed: U51.3 (SDO), U52.4 (SDI)
unnamed: U52.2 (CKO), U53.5 (CKI)
unnamed: U52.3 (SDO), U53.4 (SDI)
unnamed: U53.2 (CKO), U54.5 (CKI)
unnamed: U53.3 (SDO), U54.4 (SDI)
unnamed: U54.2 (CKO), U55.5 (CKI)
unnamed: U54.3 (SDO), U55.4 (SDI)
unnamed: U55.2 (CKO), U56.5 (CKI)
unnamed: U55.3 (SDO), U56.4 (SDI)
unnamed: U56.2 (CKO), U57.5 (CKI)
unnamed: U56.3 (SDO), U57.4 (SDI)
unnamed: U57.2 (CKO), U58.5 (CKI)
unnamed: U57.3 (SDO), U58.4 (SDI)
unnamed: U58.2 (CKO), U59.5 (CKI)
unnamed: U58.3 (SDO), U59.4 (SDI)
unnamed: U59.2 (CKO), U60.5 (CKI)
unnamed: U59.3 (SDO), U60.4 (SDI)
unnamed: U60.2 (CKO), U61.5 (CKI)
unnamed: U60.3 (SDO), U61.4 (SDI)
unnamed: U61.2 (CKO), U62.5 (CKI)
unnamed: U61.3 (SDO), U62.4 (SDI)
unnamed: U62.2 (CKO), U63.5 (CKI)
unnamed: U62.3 (SDO), U63.4 (SDI)
unnamed: U63.2 (CKO), U64.5 (CKI)
unnamed: U63.3 (SDO), U64.4 (SDI)
unnamed: U65.2 (CKO), U66.5 (CKI)
unnamed: U65.3 (SDO), U66.4 (SDI)
unnamed: U66.2 (CKO), U67.5 (CKI)
unnamed: U66.3 (SDO), U67.4 (SDI)
unnamed: U67.2 (CKO), U68.5 (CKI)
unnamed: U67.3 (SDO), U68.4 (SDI)
unnamed: U68.2 (CKO), U69.5 (CKI)
unnamed: U68.3 (SDO), U69.4 (SDI)
unnamed: U69.2 (CKO), U70.5 (CKI)
unnamed: U69.3 (SDO), U70.4 (SDI)
unnamed: U70.2 (CKO), U71.5 (CKI)
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

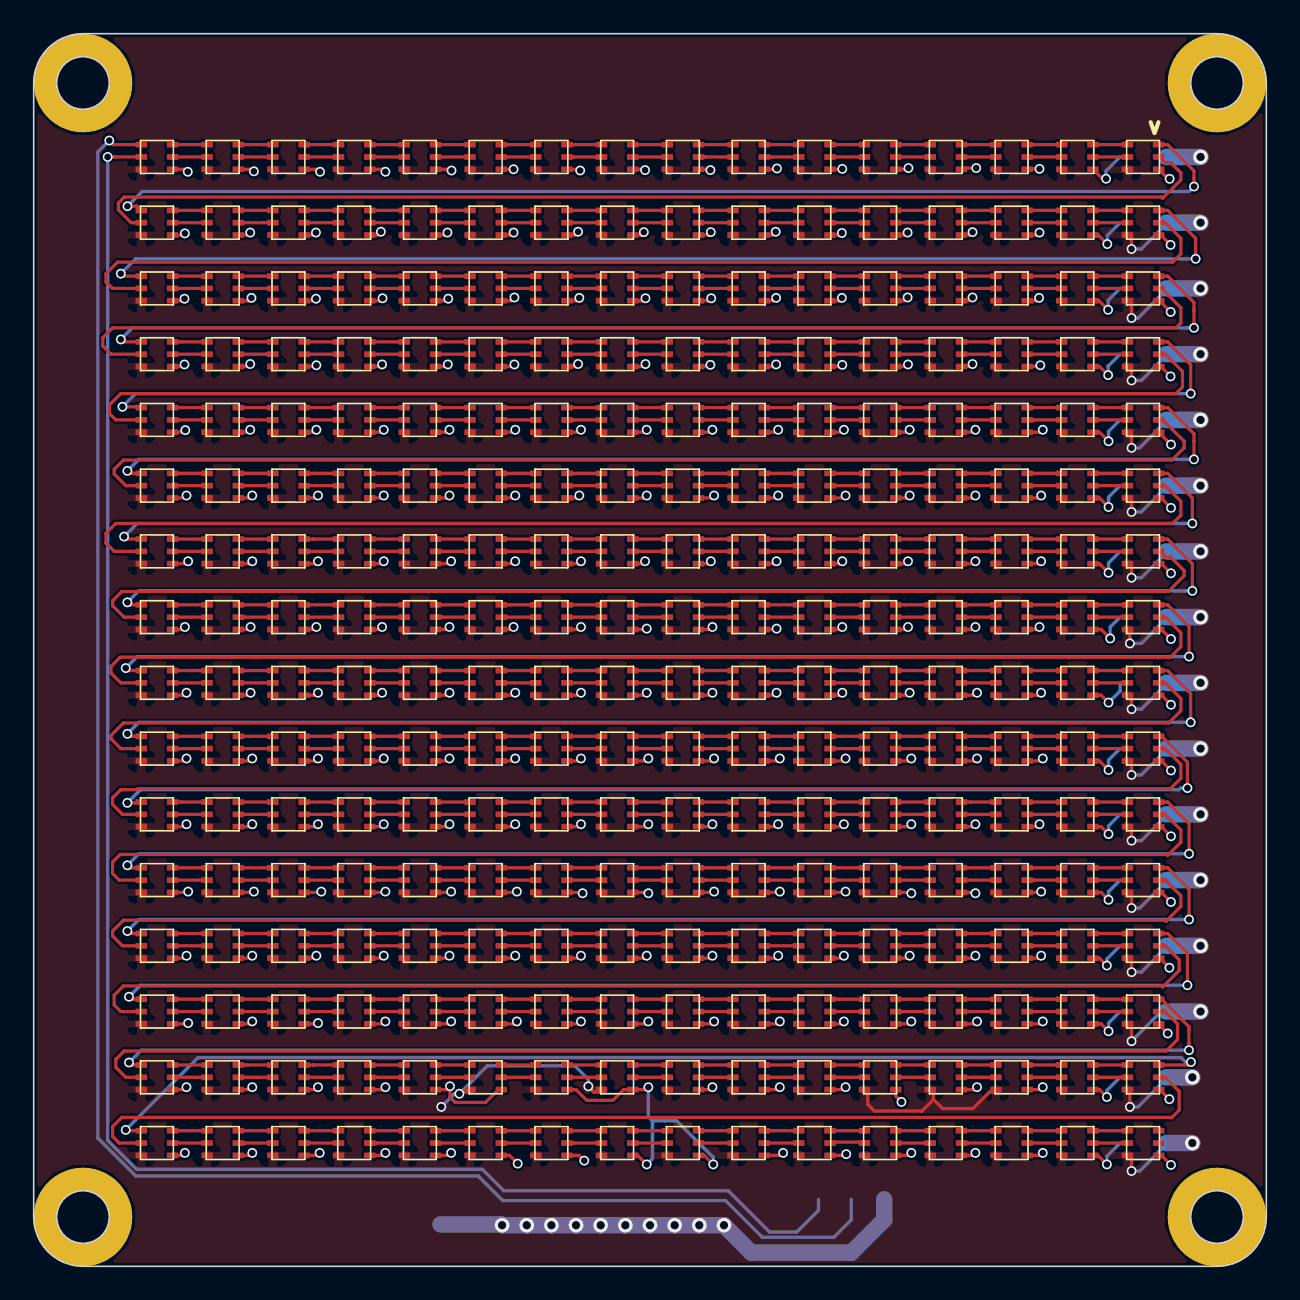
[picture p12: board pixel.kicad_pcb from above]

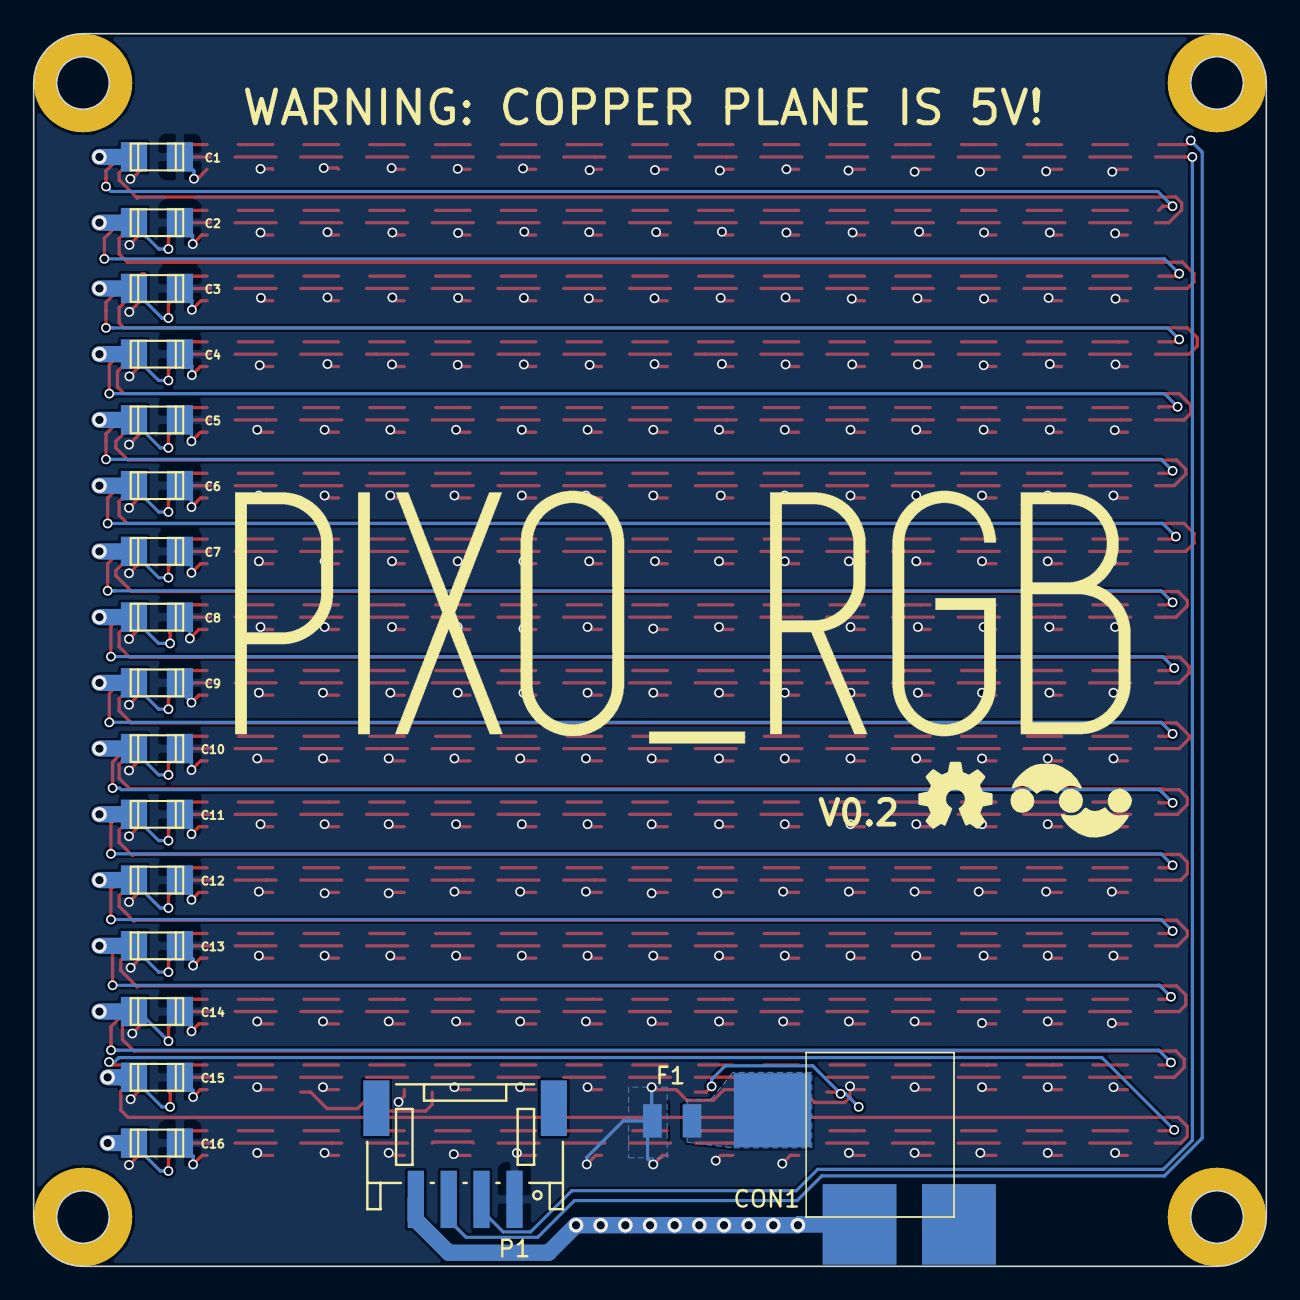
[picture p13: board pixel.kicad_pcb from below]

Board: 2 copper layers, 75.0 x 75.0 mm, 275 parts (19 on the bottom side), 515 nets.

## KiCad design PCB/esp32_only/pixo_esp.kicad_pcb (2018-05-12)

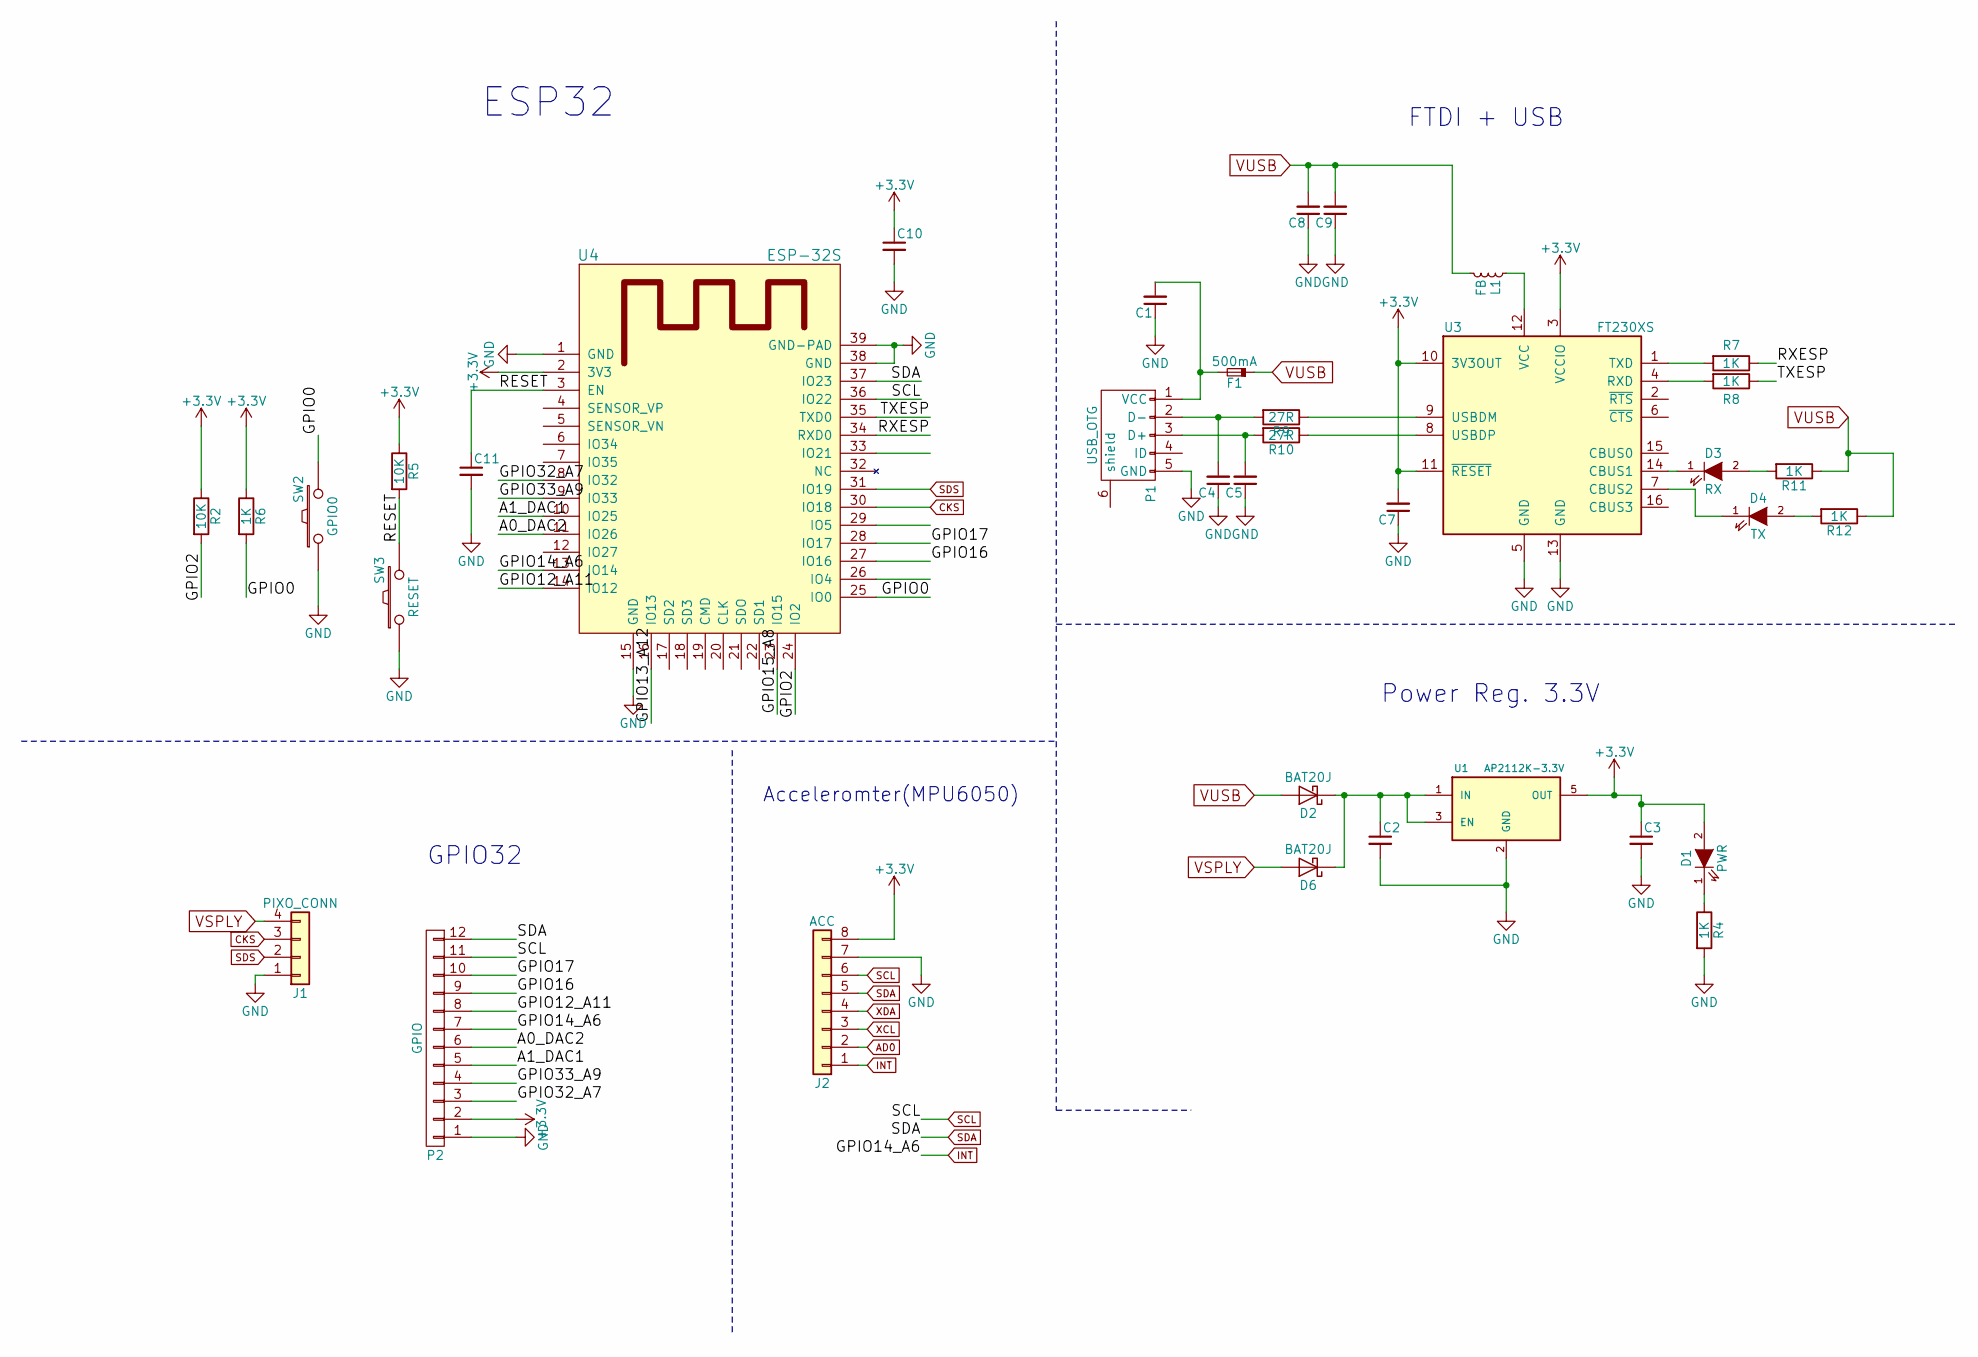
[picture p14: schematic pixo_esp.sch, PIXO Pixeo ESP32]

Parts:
C1, C7, C8: 0.1uF; C_0805; Digikey Part No. 1276-1003-1-ND
C2, C11: 1uF; C_0805; Digikey Part No. 311-1365-1-ND
C3: 2.2uF; C_0805; Digikey Part No. 490-3336-1-ND
C4, C5: 47pF; C_0805; Digikey Part No. 1276-1156-1-ND
C9: 10uF; C_0805; Digikey Part No. 1276-1003-1-ND
C10: 10uF; C_0805; Digikey Part No. 490-3340-1-ND
D1: PWR; Led_0603; Digikey Part No. 160-1447-1-ND
D2, D6: BAT20J; sod323; Digikey Part No. 497-3381-1-ND
D3: RX; Led_0603; Digikey Part No. 160-1448-1-ND
D4: TX; Led_0603; Digikey Part No. 160-1446-1-ND
F1: 500mA; c_1206; Digikey Part No. 507-1802-1-ND
J1: PIXO_CONN; Connectors_JST_S4B-PH-SM4-TB; Digikey Part No. 455-1751-1-ND
J2: ACC; Pin_Header_Straight_1x08; Digikey Part No. S7006-ND
L1: FB; R_0805_HandSoldering; Digikey Part No. 240-2390-1-ND
P1: USB_OTG; USB_Micro-B; Digikey Part No. 609-4618-1-ND
P2: GPIO; Pin_Header_Straight_1x12
R2, R5: 10K; R_0805; Digikey Part No. RR12P10.0KDCT-ND
R4, R6, R7, R8, R11, R12: 1K; R_0805; Digikey Part No. P1.0KDACT-ND
R9, R10: 27R; R_0805; Digikey Part No. RHM27KCT-ND
SW2: GPIO0; PTS-LFS; Digikey Part No. CKN9112CT-ND
SW3: RESET; PTS-LFS; Digikey Part No. CKN9112CT-ND
U1: AP2112K-3.3V; SOT-23-5; Digikey Part No. AP2112K-3.3TRG1DICT-ND
U3: FT230XS; SSOP-16_3.9x4.9mm_Pitch0.635mm; Digikey Part No. 768-1135-1-ND
U4: ESP-32S

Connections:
+3V3: C3.1, C7.2, C10.1, D1.2 (A), J2.8, P2.2, R2.1, R5.1, R6.1, U1.5 (OUT), U3.3 (VCCIO), U3.10 (3V3OUT), U3.11 (~RESET), U4.2 (3V3)
/A0_DAC2: P2.6, U4.11 (IO26)
/A1_DAC1: P2.5, U4.10 (IO25)
/GPIO0: R6.2, SW2.2, U4.25 (IO0)
/GPIO2: R2.2, U4.24 (IO2)
/GPIO12_A11: P2.8, U4.14 (IO12)
/GPIO13_A12: U4.16 (IO13)
/GPIO15_A8: U4.23 (IO15)
/GPIO16: P2.9, U4.27 (IO16)
/GPIO17: P2.10, U4.28 (IO17)
/GPIO32_A7: P2.3, U4.8 (IO32)
/GPIO33_A9: P2.4, U4.9 (IO33)
/RESET: C11.1, R5.2, SW3.2, U4.3 (EN)
/RXESP: R7.1, U4.34 (RXD0)
/TXESP: R8.1, U4.35 (TXD0)
AD0: J2.2
CKS: J1.3, U4.30 (IO18)
GND: C1.1, C2.2, C3.2, C4.1, C5.1, C7.1, C8.1, C9.1, C10.2, C11.2, J1.1, J2.7, P1.5 (GND), P2.1, R4.2, SW2.1, SW3.1, U1.2 (GND), U3.5 (GND), U3.13 (GND), U4.1 (GND), U4.15 (GND), U4.38 (GND), U4.39 (GND-PAD)
INT: J2.1, P2.7, U4.13 (IO14)
unnamed: C1.2, F1.2, P1.1 (VCC)
unnamed: C2.1, D2.1 (K), D6.1 (K), U1.1 (IN), U1.3 (EN)
unnamed: C4.2, P1.2 (D-), R9.2
unnamed: C5.2, P1.3 (D+), R10.2
unnamed: D1.1 (K), R4.1
unnamed: D3.1 (K), U3.14 (CBUS1)
unnamed: D3.2 (A), R11.2
unnamed: D4.1 (K), U3.7 (CBUS2)
unnamed: D4.2 (A), R12.2
unnamed: L1.1, U3.12 (VCC)
unnamed: R7.2, U3.1 (TXD)
unnamed: R8.2, U3.4 (RXD)
unnamed: R9.1, U3.9 (USBDM)
unnamed: R10.1, U3.8 (USBDP)
SCL: J2.6, P2.11, U4.36 (IO22)
SDA: J2.5, P2.12, U4.37 (IO23)
SDS: J1.2, U4.31 (IO19)
VSPLY: D6.2 (A), J1.4
VUSB: C8.2, C9.2, D2.2 (A), F1.1, L1.2, R11.1, R12.1
XCL: J2.3
XDA: J2.4

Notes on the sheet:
FTDI + USB
Power Reg. 3.3V
ESP32
GPIO32
Acceleromter(MPU6050)

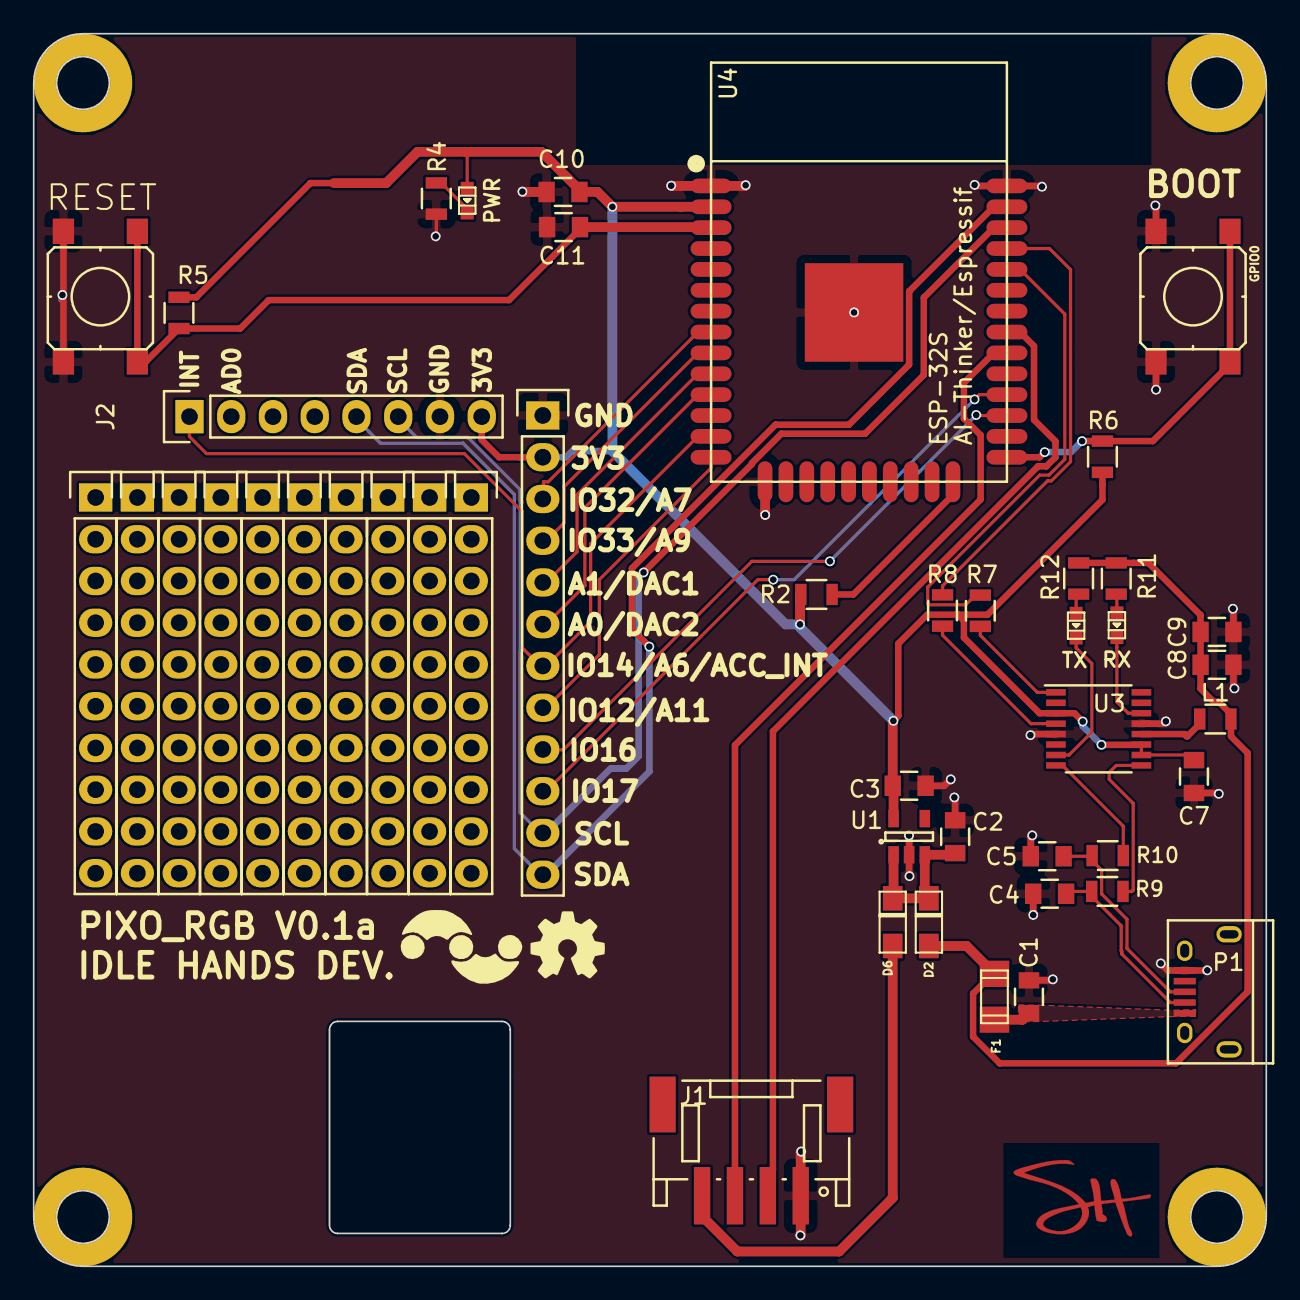
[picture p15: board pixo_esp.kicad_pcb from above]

Board: 2 copper layers, 75.0 x 75.0 mm, 36 parts (0 on the bottom side), 35 nets.

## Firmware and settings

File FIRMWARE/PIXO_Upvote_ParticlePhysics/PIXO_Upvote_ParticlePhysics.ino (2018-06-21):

//--------------------------------------------------------------------------
// This code is modified from the following Adafruit tutorial: https://learn.adafruit.com/animated-led-sand/overview
/*

    This code is modified from the following Adafruit tutorial: https://learn.adafruit.com/animated-led-sand/overview
    This program shows an upvote arrow 3 times then on the 4th it breaks into particles that will move based on accelerometer readings.
*/


#include <Wire.h>            // For I2C communication
#include <SPI.h>
#include <Adafruit_GFX.h>
#include <Adafruit_DotStarMatrix.h>
#include <Adafruit_DotStar.h>
#include <ArduinoJson.h>
#include "I2Cdev.h"
#include "MPU6050.h"



MPU6050 mpu;

uint8_t upvote[256][3] = {{0, 0, 0}, {0, 0, 0}, {0, 0, 0}, {0, 0, 0}, {0, 0, 0}, {0, 0, 0}, {0, 0, 0}, {0, 0, 0}, {0, 0, 0}, {0, 0, 0}, {0, 0, 0}, {0, 0, 0}, {0, 0, 0}, {0, 0, 0}, {0, 0, 0}, {0, 0, 0}, {0, 0, 0}, {0, 0, 0}, {0, 0, 0}, {0, 0, 0}, {0, 0, 0}, {0, 0, 0}, {0, 0, 0}, {255, 68, 0}, {255, 68, 0}, {0, 0, 0}, {0, 0, 0}, {0, 0, 0}, {0, 0, 0}, {0, 0, 0}, {0, 0, 0}, {0, 0, 0}, {0, 0, 0}, {0, 0, 0}, {0, 0, 0}, {0, 0, 0}, {0, 0, 0}, {0, 0, 0}, {255, 68, 0}, {255, 68, 0}, {255, 68, 0}, {255, 68, 0}, {0, 0, 0}, {0, 0, 0}, {0, 0, 0}, {0, 0, 0}, {0, 0, 0}, {0, 0, 0}, {0, 0, 0}, {0, 0, 0}, {0, 0, 0}, {0, 0, 0}, {0, 0, 0}, {255, 68, 0}, {255, 68, 0}, {255, 68, 0}, {255, 68, 0}, {255, 68, 0}, {255, 68, 0}, {0, 0, 0}, {0, 0, 0}, {0, 0, 0}, {0, 0, 0}, {0, 0, 0}, {0, 0, 0}, {0, 0, 0}, {0, 0, 0}, {0, 0, 0}, {255, 68, 0}, {255, 68, 0}, {255, 68, 0}, {255, 68, 0}, {255, 68, 0}, {255, 68, 0}, {255, 68, 0}, {255, 68, 0}, {0, 0, 0}, {0, 0, 0}, {0, 0, 0}, {0, 0, 0}, {0, 0, 0}, {0, 0, 0}, {0, 0, 0}, {255, 68, 0}, {255, 68, 0}, {255, 68, 0}, {255, 68, 0}, {255, 68, 0}, {255, 68, 0}, {255, 68, 0}, {255, 68, 0}, {255, 68, 0}, {255, 68, 0}, {0, 0, 0}, {0, 0, 0}, {0, 0, 0}, {0, 0, 0}, {0, 0, 0}, {255, 68, 0}, {255, 68, 0}, {255, 68, 0}, {255, 68, 0}, {255, 68, 0}, {255, 68, 0}, {255, 68, 0}, {255, 68, 0}, {255, 68, 0}, {255, 68, 0}, {255, 68, 0}, {255, 68, 0}, {0, 0, 0}, {0, 0, 0}, {0, 0, 0}, {255, 68, 0}, {255, 68, 0}, {255, 68, 0}, {255, 68, 0}, {255, 68, 0}, {255, 68, 0}, {255, 68, 0}, {255, 68, 0}, {255, 68, 0}, {255, 68, 0}, {255, 68, 0}, {255, 68, 0}, {255, 68, 0}, {255, 68, 0}, {0, 0, 0}, {255, 68, 0}, {255, 68, 0}, {255, 68, 0}, {255, 68, 0}, {255, 68, 0}, {255, 68, 0}, {255, 68, 0}, {255, 68, 0}, {255, 68, 0}, {255, 68, 0}, {255, 68, 0}, {255, 68, 0}, {255, 68, 0}, {255, 68, 0}, {255, 68, 0}, {255, 68, 0}, {0, 0, 0}, {0, 0, 0}, {0, 0, 0}, {0, 0, 0}, {0, 0, 0}, {255, 68, 0}, {255, 68, 0}, {255, 68, 0}, {255, 68, 0}, {255, 68, 0}, {255, 68, 0}, {0, 0, 0}, {0, 0, 0}, {0, 0, 0}, {0, 0, 0}, {0, 0, 0}, {0, 0, 0}, {0, 0, 0}, {0, 0, 0}, {0, 0, 0}, {0, 0, 0}, {255, 68, 0}, {255, 68, 0}, {255, 68, 0}, {255, 68, 0}, {255, 68, 0}, {255, 68, 0}, {0, 0, 0}, {0, 0, 0}, {0, 0, 0}, {0, 0, 0}, {0, 0, 0}, {0, 0, 0}, {0, 0, 0}, {0, 0, 0}, {0, 0, 0}, {0, 0, 0}, {255, 68, 0}, {255, 68, 0}, {255, 68, 0}, {255, 68, 0}, {255, 68, 0}, {255, 68, 0}, {0, 0, 0}, {0, 0, 0}, {0, 0, 0}, {0, 0, 0}, {0, 0, 0}, {0, 0, 0}, {0, 0, 0}, {0, 0, 0}, {0, 0, 0}, {0, 0, 0}, {255, 68, 0}, {255, 68, 0}, {255, 68, 0}, {255, 68, 0}, {255, 68, 0}, {255, 68, 0}, {0, 0, 0}, {0, 0, 0}, {0, 0, 0}, {0, 0, 0}, {0, 0, 0}, {0, 0, 0}, {0, 0, 0}, {0, 0, 0}, {0, 0, 0}, {0, 0, 0}, {255, 68, 0}, {255, 68, 0}, {255, 68, 0}, {255, 68, 0}, {255, 68, 0}, {255, 68, 0}, {0, 0, 0}, {0, 0, 0}, {0, 0, 0}, {0, 0, 0}, {0, 0, 0}, {0, 0, 0}, {0, 0, 0}, {0, 0, 0}, {0, 0, 0}, {0, 0, 0}, {255, 68, 0}, {255, 68, 0}, {255, 68, 0}, {255, 68, 0}, {255, 68, 0}, {255, 68, 0}, {0, 0, 0}, {0, 0, 0}, {0, 0, 0}, {0, 0, 0}, {0, 0, 0}, {0, 0, 0}, {0, 0, 0}, {0, 0, 0}, {0, 0, 0}, {0, 0, 0}, {255, 68, 0}, {255, 68, 0}, {255, 68, 0}, {255, 68, 0}, {255, 68, 0}, {255, 68, 0}, {0, 0, 0}, {0, 0, 0}, {0, 0, 0}, {0, 0, 0}, {0, 0, 0}};
int sh[256][3] = {{0, 0, 0}, {0, 0, 0}, {0, 0, 0}, {0, 0, 0}, {0, 0, 0}, {0, 0, 0}, {0, 0, 0}, {0, 0, 0}, {0, 0, 0}, {0, 0, 0}, {0, 0, 0}, {0, 0, 0}, {0, 0, 0}, {0, 0, 0}, {0, 0, 0}, {0, 0, 0}, {0, 0, 0}, {0, 0, 0}, {1, 1, 1}, {2, 2, 2}, {3, 3, 3}, {3, 3, 3}, {2, 2, 2}, {0, 0, 0}, {0, 0, 0}, {0, 0, 0}, {0, 0, 0}, {0, 0, 0}, {0, 0, 0}, {0, 0, 0}, {0, 0, 0}, {0, 0, 0}, {3, 3, 3}, {3, 3, 3}, {0, 0, 0}, {0, 0, 0}, {0, 0, 0}, {0, 0, 0}, {0, 0, 0}, {0, 0, 0}, {0, 0, 0}, {0, 0, 0}, {0, 0, 0}, {0, 0, 0}, {0, 0, 0}, {0, 0, 0}, {0, 0, 0}, {0, 0, 0}, {0, 0, 0}, {0, 0, 0}, {22, 22, 22}, {58, 58, 58}, {78, 78, 78}, {86, 86, 86}, {69, 69, 69}, {5, 5, 5}, {1, 1, 1}, {3, 3, 3}, {0, 0, 0}, {2, 2, 2}, {0, 0, 0}, {0, 0, 0}, {0, 0, 0}, {0, 0, 0}, {86, 86, 86}, {154, 154, 154}, {114, 114, 114}, {73, 73, 73}, {49, 49, 49}, {40, 40, 40}, {39, 39, 39}, {6, 6, 6}, {0, 0, 0}, {0, 0, 0}, {0, 0, 0}, {0, 0, 0}, {0, 0, 0}, {0, 0, 0}, {0, 0, 0}, {0, 0, 0}, {93, 93, 93}, {163, 163, 163}, {118, 118, 118}, {65, 65, 65}, {17, 17, 17}, {0, 0, 0}, {0, 0, 0}, {1, 1, 1}, {14, 14, 14}, {52, 52, 52}, {0, 0, 0}, {35, 35, 35}, {0, 0, 0}, {2, 2, 2}, {3, 3, 3}, {2, 2, 2}, {0, 0, 0}, {0, 0, 0}, {30, 30, 30}, {74, 74, 74}, {114, 114, 114}, {122, 122, 122}, {54, 54, 54}, {0, 0, 0}, {21, 21, 21}, {211, 211, 211}, {4, 4, 4}, {174, 174, 174}, {48, 48, 48}, {0, 0, 0}, {0, 0, 0}, {0, 0, 0}, {3, 3, 3}, {2, 2, 2}, {0, 0, 0}, {0, 0, 0}, {0, 0, 0}, {32, 32, 32}, {131, 131, 131}, {108, 108, 108}, {0, 0, 0}, {183, 183, 183}, {38, 38, 38}, {136, 136, 136}, {130, 130, 130}, {41, 41, 41}, {75, 75, 75}, {78, 78, 78}, {0, 0, 0}, {0, 0, 0}, {2, 2, 2}, {0, 0, 0}, {0, 0, 0}, {20, 20, 20}, {51, 51, 51}, {199, 199, 199}, {152, 152, 152}, {199, 199, 199}, {116, 116, 116}, {110, 110, 110}, {193, 193, 193}, {51, 51, 51}, {46, 46, 46}, {25, 25, 25}, {0, 0, 0}, {1, 1, 1}, {0, 0, 0}, {61, 61, 61}, {154, 154, 154}, {123, 123, 123}, {76, 76, 76}, {53, 53, 53}, {173, 173, 173}, {155, 155, 155}, {123, 123, 123}, {0, 0, 0}, {181, 181, 181}, {4, 4, 4}, {0, 0, 0}, {0, 0, 0}, {2, 2, 2}, {0, 0, 0}, {49, 49, 49}, {209, 209, 209}, {32, 32, 32}, {0, 0, 0}, {0, 0, 0}, {117, 117, 117}, {126, 126, 126}, {53, 53, 53}, {135, 135, 135}, {1, 1, 1}, {134, 134, 134}, {63, 63, 63}, {2, 2, 2}, {3, 3, 3}, {1, 1, 1}, {1, 1, 1}, {24, 24, 24}, {124, 124, 124}, {87, 87, 87}, {75, 75, 75}, {126, 126, 126}, {143, 143, 143}, {11, 11, 11}, {0, 0, 0}, {0, 0, 0}, {0, 0, 0}, {53, 53, 53}, {126, 126, 126}, {0, 0, 0}, {3, 3, 3}, {0, 0, 0}, {0, 0, 0}, {0, 0, 0}, {0, 0, 0}, {25, 25, 25}, {35, 35, 35}, {24, 24, 24}, {0, 0, 0}, {0, 0, 0}, {2, 2, 2}, {3, 3, 3}, {0, 0, 0}, {0, 0, 0}, {35, 35, 35}, {0, 0, 0}, {0, 0, 0}, {0, 0, 0}, {0, 0, 0}, {1, 1, 1}, {2, 2, 2}, {0, 0, 0}, {0, 0, 0}, {0, 0, 0}, {3, 3, 3}, {1, 1, 1}, {0, 0, 0}, {0, 0, 0}, {0, 0, 0}, {0, 0, 0}, {0, 0, 0}, {0, 0, 0}, {0, 0, 0}, {0, 0, 0}, {0, 0, 0}, {0, 0, 0}, {0, 0, 0}, {1, 1, 1}, {1, 1, 1}, {1, 1, 1}, {0, 0, 0}, {0, 0, 0}, {0, 0, 0}, {0, 0, 0}, {0, 0, 0}, {0, 0, 0}, {1, 1, 1}, {0, 0, 0}, {0, 0, 0}, {0, 0, 0}, {0, 0, 0}, {0, 0, 0}, {0, 0, 0}, {0, 0, 0}, {0, 0, 0}, {0, 0, 0}, {0, 0, 0}, {0, 0, 0}, {0, 0, 0}, {0, 0, 0}, {0, 0, 0}, {0, 0, 0}, {0, 0, 0}, {0, 0, 0}, {0, 0, 0}};

//int N_GRAINS = 0;
#define N_GRAINS     58 // Number of grains of sand
#define WIDTH        16 // Display width in pixels
#define HEIGHT       16 // Display height in pixels
#define MAX_FPS      45 
#define SCALE        128
#define WBOUNCE      -2
#define BBOUNCE      -2

#define MAX_X (WIDTH  * SCALE - 1) 
#define MAX_Y (HEIGHT * SCALE - 1) 
struct Grain {
  int16_t  x,  y; 
  int16_t vx, vy; 
} grain[N_GRAINS];

int16_t rax, ray, raz;
int16_t rgx, rgy, rgz;
uint32_t        prevTime   = 0;      
uint8_t         backbuffer = 0,      
                img[WIDTH * HEIGHT];



#define DATAPIN    19
#define CLOCKPIN   18


#define SHIFTDELAY 30
#define BRIGHTNESS 20



Adafruit_DotStarMatrix matrix = Adafruit_DotStarMatrix(
                                  16, 16, DATAPIN, CLOCKPIN,
                                  DS_MATRIX_TOP    + DS_MATRIX_LEFT +
                                  DS_MATRIX_ROWS + DS_MATRIX_PROGRESSIVE,
                                  DOTSTAR_BGR);


void setup(void) {
  uint8_t i, j, bytes;
  Serial.begin(115200);

#if I2CDEV_IMPLEMENTATION == I2CDEV_ARDUINO_WIRE
  Wire.begin();
#elif I2CDEV_IMPLEMENTATION == I2CDEV_BUILTIN_FASTWIRE
  Fastwire::setup(400, true);
#endif
  Serial.println("Initializing I2C devices...");
  mpu.initialize();
  Serial.println("Testing device connections...");
  Serial.println(mpu.testConnection() ? "MPU6050 connection successful" : "MPU6050 connection failed");

  matrix.begin();
  matrix.setBrightness(BRIGHTNESS);

  notification();
  notificationhalf();

  memset(img, 0, sizeof(img)); // Clear the img[] array
  int grain_num = 0;
  for (int x = 0; x < 256; x++) {
    if (sh[x][0] > 50) {

      int NX = x % 16;
      int NY = x / 16;
      grain[grain_num].x = (NX  * SCALE); // Assign random position within
      grain[grain_num].y = (NY * SCALE);
      grain_num++;
    }
  }

  for (i = 0; i < N_GRAINS; i++) { // For each sand grain...
    img[(grain[i].y / SCALE) * WIDTH + (grain[i].x / SCALE)] = 255; // Mark it
    grain[i].vx = grain[i].vy = 0; // Initial velocity is zero
  }
}


void loop() {

  uint32_t t;
  while (((t = micros()) - prevTime) < (1000000L / MAX_FPS));
  prevTime = t;


  backbuffer = 1 - backbuffer; // Swap front/back buffer index

  // Read accelerometer...
  mpu.getMotion6(&rax, &ray, &raz, &rgx, &rgy, &rgz);
  randomSeed(A7);

  int16_t ax = -ray / SCALE,      // Transform accelerometer axes
          ay = -rax / SCALE,      // to grain coordinate space
          az = abs(raz) / 128; // Random motion factor

  az = (az >= 3) ? 1 : 4 - az;      // Clip & invert
  ax -= az;                         // Subtract motion factor from X, Y
  ay -= az;
  long az2 = az * 2 + 1;         // Range of random motion to add back in


  int32_t v2; // Velocity squared
  float   v;  // Absolute velocity
  for (int i = 0; i < N_GRAINS; i++) {
    grain[i].vx += ax + random(az2); // A little randomness makes
    grain[i].vy += ay + random(az2); // tall stacks topple better!

    v2 = (int32_t)grain[i].vx * grain[i].vx + (int32_t)grain[i].vy * grain[i].vy;
    if (v2 > 65536) { // If v^2 > 65536, then v > SCALE
      v = sqrt((float)v2); // Velocity vector magnitude
      grain[i].vx = (int)(SCALE * (float)grain[i].vx / v); // Maintain heading
      grain[i].vy = (int)(SCALE * (float)grain[i].vy / v); // Limit magnitude
    }
  }

  uint8_t        i, bytes, oldidx, newidx, delta;
  int16_t        newx, newy;
  // const uint8_t *ptr = remap;

  randomSeed(A7);
  int list[N_GRAINS];
  for (int num = 0; num < N_GRAINS; num++) {
    list[num] = num;
  }
  for (int a = 0; a < N_GRAINS; a++)
  {
    int r = random(a, (N_GRAINS));
    int temp = list[a];
    list[a] = list[r];
    list[r] = temp;
  }

  for (int num = 0; num < N_GRAINS; num++) {
    Serial.print(list[num]);
    Serial.print(", ");
  }
  Serial.println(",,Done.");
  for (i = 0; i < N_GRAINS; i++) {
    newx = grain[list[i]].x + grain[list[i]].vx;
    newy = grain[list[i]].y + grain[list[i]].vy;
    if (newx > MAX_X) {
      newx         = MAX_X;
      grain[list[i]].vx /= WBOUNCE;
    } else if (newx < 0) {
      newx         = 0;
      grain[list[i]].vx /= WBOUNCE;
    }
    if (newy > MAX_Y) {
      newy         = MAX_Y;
      grain[list[i]].vy /= WBOUNCE;
    } else if (newy < 0) {
      newy         = 0;
      grain[list[i]].vy /= WBOUNCE;
    }

    oldidx = (grain[list[i]].y / SCALE) * WIDTH + (grain[list[i]].x / SCALE);
    newidx = (newy      / SCALE) * WIDTH + (newx      / SCALE);
    if ((oldidx != newidx) &&
        img[newidx]) {
      delta = abs(newidx - oldidx);
      if (delta == 1) {
        newx         = grain[list[i]].x;
        grain[list[i]].vx /= BBOUNCE;
        newidx       = oldidx;
      } else if (delta == WIDTH) {
        newy         = grain[list[i]].y;
        grain[list[i]].vy /= BBOUNCE;
        newidx       = oldidx;
      } else {

        if ((abs(grain[list[i]].vx) - abs(grain[list[i]].vy)) >= 0) {
          newidx = (grain[list[i]].y / SCALE) * WIDTH + (newx / SCALE);
          if (!img[newidx]) {
            newy         = grain[list[i]].y;
            grain[list[i]].vy /= BBOUNCE;
          } else {
            newidx = (newy / SCALE) * WIDTH + (grain[list[i]].x / SCALE);
            if (!img[newidx]) {
              newx         = grain[list[i]].x;
              grain[list[i]].vx /= BBOUNCE;
            } else {
              newx         = grain[list[i]].x;
              newy         = grain[list[i]].y;
              grain[list[i]].vx /= BBOUNCE;
              grain[list[i]].vy /= BBOUNCE;
              newidx       = oldidx;
            }
          }
        } else {
          newidx = (newy / SCALE) * WIDTH + (grain[list[i]].x / SCALE);
          if (!img[newidx]) {
            newx         = grain[list[i]].x;
            grain[list[i]].vy /= BBOUNCE;
          } else {
            newidx = (grain[list[i]].y / SCALE) * WIDTH + (newx / SCALE);
            if (!img[newidx]) {
              newy         = grain[list[i]].y;
              grain[list[i]].vy /= BBOUNCE;
            } else {
              newx         = grain[list[i]].x;
              newy         = grain[list[i]].y;
              grain[list[i]].vx /= BBOUNCE;
              grain[list[i]].vy /= BBOUNCE;
              newidx       = oldidx;
            }
          }
        }
      }
    }
    grain[list[i]].x  = newx;
    grain[list[i]].y  = newy;
    img[oldidx] = 0;
    img[newidx] = 255;

  }
  matrix.fillScreen(0);
  for (int i = 0; i < N_GRAINS; i++) {
    int x = grain[i].x / SCALE;
    int y = grain[i].y / SCALE;
    matrix.drawPixel(x, y, matrix.Color(150, 150, 150));
  }
  matrix.show();



}

void notificationhalf() {
  for (int j = 15; j >= 0; j--) {
    matrix.fillScreen(0);
    for (int i = 0; i < 256; i++) {
      matrix.setPixelColor(i + (j * 16), sh[i][0], sh[i][1], sh[i][2]);
    }
    matrix.show();
    delay(15);
  }
  delay(100);
}

void notification() {
  for (int j = 15; j >= 0; j--) {
    matrix.fillScreen(0);
    for (int i = 0; i < 256; i++) {
      matrix.setPixelColor(i + (j * 16), sh[i][0], sh[i][1], sh[i][2]);
    }
    matrix.show();
    delay(15);
  }
  delay(700);
  for (int j = 0; j >= -16; j--) {
    matrix.fillScreen(0);
    for (int i = 0; i < 256; i++) {
      matrix.setPixelColor(i + (j * 16),sh[i][0], sh[i][1], sh[i][2]);
    }
    matrix.show();
    delay(15);
  }
  delay(500);
  matrix.fillScreen(0);
  matrix.show();
}

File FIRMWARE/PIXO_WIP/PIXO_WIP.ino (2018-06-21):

/*
   PIXO Pixel WIP Test Program
   This program is a work in progress but will let you test your LED matrix if it is working or not.
   Try out the various Demos and images in the image.h file.

   Many libraries from Adafruit are needed and can be seen below.

*/

#include <SPI.h>
#include <Adafruit_GFX.h>
#include <Adafruit_DotStarMatrix.h>
#include <Adafruit_DotStar.h>
#include <Fonts/FreeMonoOblique9pt7b.h>
#include "image.h"




#define DATAPIN    19
#define CLOCKPIN   18

char *names[] = {"Unexpected Maker",
                 "Jon Peer (Rhymes with Beer)",
                 "Ran-Dee Glenn",
                 "Stee-ven Lud-gate a.k.a. chunky steve-oh",
                 "Christian Will-helm",
                 "Dale Cousins",
                 "Roland Alvares",
                 "Abdul Aziz is my best friend",
                 "Richard Stewart",
                 "Stee-fen Goo-juh",
                 "Alexandru Stan",
                 "Brad Pow-urrs. I mean, pretty straightforward.",
                 "Code Fox",
                 "Bobby CC Wong",
                 "Tim Bye-Num",
                 "nic gill",
                 "Jonathan BET-zold",
                 "Stay-fan",
                 "Nicolai Schwarz ",
                 "Bligh-th Gar-rat",
                 "Mark S",
                 "York",
                 "Ernesto Cibrian",
                 "Dave Platts",
                 "Dj Walker-Morgan",
                 "João Miranda",
                 "Ther mound (shouldn't be too tough :) )",
                 "Reverend Alexander J Bor sick",
                 "APSoft (Hey Pea Soft)",
                 "Patrick Hah-ga-mahn",
                 "Can you say: “YouTube.com/Dubwise” pronounced “Dub-wise”.",
                 "Fabian Christ",
                 "Steve Berry-man",
                 "I feel like it's a pretty self explanatory name haha!",
                 "Noah Westwind",
                 "MUR-ID-EE-N WIT",
                 "Troy Holten",
                 "Grant Patterson",
                 "Ta-tee Wall-er",
                 "Ryan Burrow",
                 "ay-vert klei-ink",
                 "leee-no veee-hen",
                 "Andrew Kind rhymes with mind",
                 "Edward Wowl-man",
                 "Simon Cleveland",
                 "Andrea Scolari",
                 "Daril Mac larin",
                 "Patrick Füglistaller",
                 "Alexandre Tron ( Like the movie , but in french :D GL ! )",
                 "Lucky 13",
                 "Dan-yul Hoff-my-stir}"
                };



int mario[256][3] = {{0, 0, 0}, {0, 0, 0}, {0, 0, 0}, {0, 0, 0}, {0, 0, 0}, {216, 0, 0}, {216, 0, 0}, {216, 0, 0}, {216, 0, 0}, {216, 0, 0}, {0, 0, 0}, {0, 0, 0}, {0, 0, 0}, {0, 0, 0}, {0, 0, 0}, {0, 0, 0}, {0, 0, 0}, {0, 0, 0}, {0, 0, 0}, {0, 0, 0}, {216, 0, 0}, {216, 0, 0}, {216, 0, 0}, {216, 0, 0}, {216, 0, 0}, {216, 0, 0}, {216, 0, 0}, {216, 0, 0}, {216, 0, 0}, {0, 0, 0}, {0, 0, 0}, {0, 0, 0}, {0, 0, 0}, {0, 0, 0}, {0, 0, 0}, {0, 0, 0}, {112, 104, 0}, {112, 104, 0}, {112, 104, 0}, {248, 171, 0}, {248, 171, 0}, {112, 104, 0}, {248, 171, 0}, {0, 0, 0}, {0, 0, 0}, {0, 0, 0}, {0, 0, 0}, {0, 0, 0}, {0, 0, 0}, {0, 0, 0}, {0, 0, 0}, {112, 104, 0}, {248, 171, 0}, {112, 104, 0}, {248, 171, 0}, {248, 171, 0}, {248, 171, 0}, {112, 104, 0}, {248, 171, 0}, {248, 171, 0}, {248, 171, 0}, {0, 0, 0}, {0, 0, 0}, {0, 0, 0}, {0, 0, 0}, {0, 0, 0}, {0, 0, 0}, {112, 104, 0}, {248, 171, 0}, {112, 104, 0}, {112, 104, 0}, {248, 171, 0}, {248, 171, 0}, {248, 171, 0}, {112, 104, 0}, {248, 171, 0}, {248, 171, 0}, {248, 171, 0}, {0, 0, 0}, {0, 0, 0}, {0, 0, 0}, {0, 0, 0}, {0, 0, 0}, {112, 104, 0}, {112, 104, 0}, {248, 171, 0}, {248, 171, 0}, {248, 171, 0}, {248, 171, 0}, {112, 104, 0}, {112, 104, 0}, {112, 104, 0}, {112, 104, 0}, {0, 0, 0}, {0, 0, 0}, {0, 0, 0}, {0, 0, 0}, {0, 0, 0}, {0, 0, 0}, {0, 0, 0}, {0, 0, 0}, {248, 171, 0}, {248, 171, 0}, {248, 171, 0}, {248, 171, 0}, {248, 171, 0}, {248, 171, 0}, {248, 171, 0}, {0, 0, 0}, {0, 0, 0}, {0, 0, 0}, {0, 0, 0}, {0, 0, 0}, {0, 0, 0}, {0, 0, 0}, {0, 0, 0}, {112, 104, 0}, {112, 104, 0}, {216, 0, 0}, {112, 104, 0}, {112, 104, 0}, {216, 0, 0}, {0, 0, 0}, {0, 0, 0}, {0, 0, 0}, {0, 0, 0}, {0, 0, 0}, {0, 0, 0}, {0, 0, 0}, {0, 0, 0}, {0, 0, 0}, {112, 104, 0}, {112, 104, 0}, {112, 104, 0}, {216, 0, 0}, {112, 104, 0}, {112, 104, 0}, {216, 0, 0}, {112, 104, 0}, {112, 104, 0}, {112, 104, 0}, {0, 0, 0}, {0, 0, 0}, {0, 0, 0}, {0, 0, 0}, {0, 0, 0}, {112, 104, 0}, {112, 104, 0}, {112, 104, 0}, {112, 104, 0}, {216, 0, 0}, {216, 0, 0}, {216, 0, 0}, {216, 0, 0}, {112, 104, 0}, {112, 104, 0}, {112, 104, 0}, {112, 104, 0}, {0, 0, 0}, {0, 0, 0}, {0, 0, 0}, {0, 0, 0}, {248, 171, 0}, {248, 171, 0}, {112, 104, 0}, {216, 0, 0}, {248, 171, 0}, {216, 0, 0}, {216, 0, 0}, {248, 171, 0}, {216, 0, 0}, {112, 104, 0}, {248, 171, 0}, {248, 171, 0}, {0, 0, 0}, {0, 0, 0}, {0, 0, 0}, {0, 0, 0}, {248, 171, 0}, {248, 171, 0}, {248, 171, 0}, {216, 0, 0}, {216, 0, 0}, {216, 0, 0}, {216, 0, 0}, {216, 0, 0}, {216, 0, 0}, {248, 171, 0}, {248, 171, 0}, {248, 171, 0}, {0, 0, 0}, {0, 0, 0}, {0, 0, 0}, {0, 0, 0}, {248, 171, 0}, {248, 171, 0}, {216, 0, 0}, {216, 0, 0}, {216, 0, 0}, {216, 0, 0}, {216, 0, 0}, {216, 0, 0}, {216, 0, 0}, {216, 0, 0}, {248, 171, 0}, {248, 171, 0}, {0, 0, 0}, {0, 0, 0}, {0, 0, 0}, {0, 0, 0}, {0, 0, 0}, {0, 0, 0}, {216, 0, 0}, {216, 0, 0}, {216, 0, 0}, {0, 0, 0}, {0, 0, 0}, {216, 0, 0}, {216, 0, 0}, {216, 0, 0}, {0, 0, 0}, {0, 0, 0}, {0, 0, 0}, {0, 0, 0}, {0, 0, 0}, {0, 0, 0}, {0, 0, 0}, {112, 104, 0}, {112, 104, 0}, {112, 104, 0}, {0, 0, 0}, {0, 0, 0}, {0, 0, 0}, {0, 0, 0}, {112, 104, 0}, {112, 104, 0}, {112, 104, 0}, {0, 0, 0}, {0, 0, 0}, {0, 0, 0}, {0, 0, 0}, {0, 0, 0}, {112, 104, 0}, {112, 104, 0}, {112, 104, 0}, {112, 104, 0}, {0, 0, 0}, {0, 0, 0}, {0, 0, 0}, {0, 0, 0}, {112, 104, 0}, {112, 104, 0}, {112, 104, 0}, {112, 104, 0}, {0, 0, 0}, {0, 0, 0}};
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

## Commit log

2018-01-31 added initial files, need some changes
    [pixel-B.Cu.gbr, pixel-B.Mask.gbr, pixel-B.Paste.gbr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]
2018-02-01 added rough sample firmware
2018-02-21 added fuse, fixed traces
    [pixel.kicad_pcb, pixel.sch]
2018-02-21 added accelerometer, changed GPIO
    [pixo_esp.kicad_pcb, pixo_esp.sch]
2018-02-21 widened keepout for antenna
    [pixo_esp.kicad_pcb]
2018-05-12 changed led pad layout
    [pixel.kicad_pcb, pixel.sch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]
2018-06-21 LED Layout Modified
    [pixel-B.Cu.gbr, pixel-B.Mask.gbr, pixel-B.Paste.gbr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]
2018-06-21 updated BOM and small fixes
    [_saved_pixo_esp.sch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]
2018-06-23 Added Case directory with a 3D printable case
    [PIXO_Bezel.stl, PIXO_Case.stl]
2018-06-28 added dxf files of boards
    [PIXO_ESP.dxf, PIXO_Pixel.dxf]
2018-07-05 Add instructions for patching i2cdev and mpu6050
